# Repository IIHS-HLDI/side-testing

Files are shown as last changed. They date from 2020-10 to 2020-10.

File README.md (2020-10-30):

# Side testing

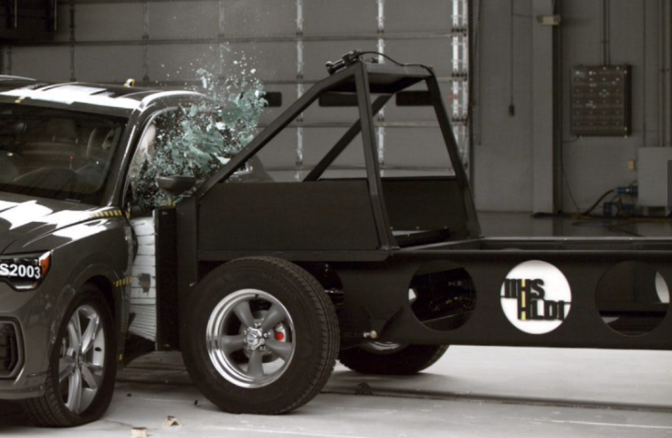
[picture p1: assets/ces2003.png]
Image of a crash test


This repository contains supporting documentation for the IIHS side impact crash test program.

## [2.0](2.0) - October 2020

In late 2020, the Institute began side impact testing using a new "2.0" protocol, which
features an improved impact cart and an impact speed of 60 km/h. This directory contains documentation
regarding the new protocol and manufacturing specs for the new impact cart.

## [1.0](1.0) - 2003 to 2020

This directory contains documentation regarding the Institute's original side impact crash test
program, in place since its inception in 2003.

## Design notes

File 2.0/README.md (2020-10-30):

# Side testing 2.0

In late 2020, the Institute began side impact testing using a new "2.0" protocol. The new protocol
features an improved impact cart traveling at 60 km/h, up from 50 km/h in the original side test protocol.

## Test protocol

- [Side impact 2.0 crash test protocol](Side%20impact%202.0%20test%20protocol.pdf) Version 1 (October 2020)

## Specifications

- [Moving deformable barrier 2.0 specification](Moving%20deformable%20barrier%20spec.pdf) Version 1 (October 2020)

## Impact cart design

- [Drawing package](Impact%20Cart/Drawing%20package.pdf)
- [Solid model](Impact%20Cart/Impact%20Cart%20with%20Suspension.STEP); Step A203 file of entire assembly for import
  into any 3D CAD software.
- DXF files for CNC plate cutting:
  - [Bent plate side channel](Impact%20Cart/Bent%20Plate%20Side%20Channel.DXF)
  - [Control arm tab](Impact%20Cart/Control%20Arm%20Tab.DXF)
  - [Low shock mounting plate](Impact%20Cart/Low%20Shock%20Mt%20Plate.DXF)
  - [Lower barrier stanchion gusset](Impact%20Cart/Lower%20Barrier%20Stanchion%20Gusset.DXF)
  - [Lower control frame tab](Impact%20Cart/Lower%20Control%20Frame%20Tab.DXF)
  - [Lower frame mount support](Impact%20Cart/Lower%20Frame%20Mt%20Support.DXF)
  - [Upper control frame mount](Impact%20Cart/Upper%20Control%20Frame%20Mount.DXF)
- [Detailed photos](Photos.md)

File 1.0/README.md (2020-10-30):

# Side testing 1.0

This is the Institute's original side impact test protocol dating back to 2003.

## Test protocol

- [Side impact 1.0 crash test protocol](Side%20crash%20test%20protocol%20-%20Version%20X.pdf) Version X (July 2017)

## Rating protocol

- [Rating guidelines](Rating%20guidelines.pdf) November 2016
- [Rating injury measure guidelines](Rating%20injury%20measure%20guidelines.pdf) Version III (May 2014)

## Miscellaneous

- [Moving deformable barrier specification](Moving%20deformable%20barrier%20spec.pdf)
- [Evaluation weighting principles for vehicle ratings](Weighting%20principles.pdf)
- [Outrigger assembly](Side%20impact%20outrigger%20assembly.pdf)
- [Recommended procedures for evaluating injury risk from side airbags](TWG%20side%20airbag%20evaluation%20procedures.pdf)
  July 2003; Prepared by the Side Airbag Out-of-Position Injury Technical Working Group (A joint project of Alliance,
  AIAM, AORC, and IIHS)
- [SID-IIs iliac wing](SID-IIs%20iliac%20wing.pdf) January 2007

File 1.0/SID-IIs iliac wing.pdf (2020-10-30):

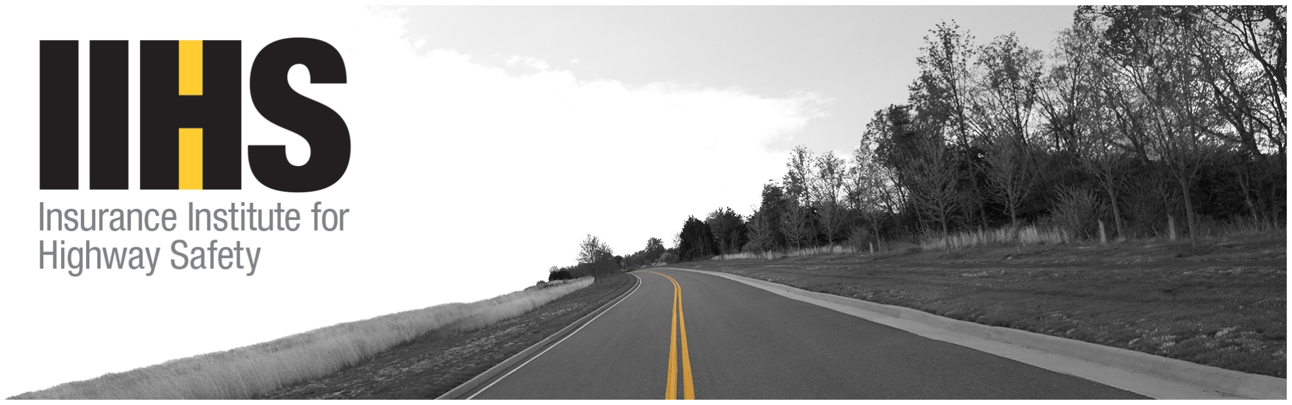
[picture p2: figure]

## Updated SID-IIs Iliac Wing

## January 2007

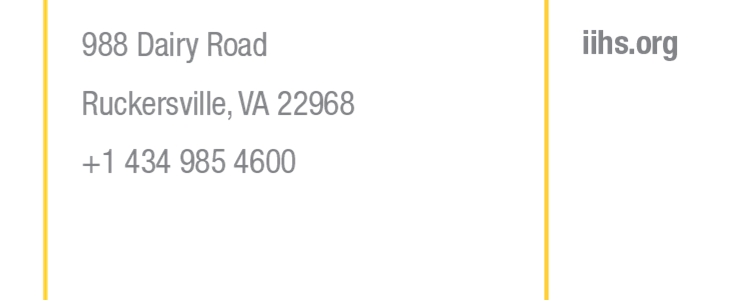
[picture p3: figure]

2007 Insurance Institute for Highway Safety | Updated SID-IIs Iliac Wing
988 Dairy Rd, Ruckersville, VA 22968. All rights reserved. | January 2007 1

Summary
A problem has been discovered with the original SID-IIs iliac wing design; the wing can deform over time and cause underreporting of iliac forces. The dummy supplier, First Technology Safety Systems (FTSS), has redesigned the wing to fix the problem. Updated iliac wings can be ordered directly from FTSS. SID-IIs dummies used in future Insurance Institute for Highway Safety (IIHS) side crash tests will have the updated iliac wing design.
Iliac Wing Load Path Issue
Problem: In the SID-IIs dummy, the iliac wing is attached to the iliac load cell with four mounting bolts. These bolts push on a thin steel plate molded into the iliac wing, which serves to distribute the load to the load cell (Figure 1). However, the plate is separated from the load cell by 3 mm (0.125 in) of urethane. Figure 2 shows a new/undeformed iliac wing mounted on a load cell (the areas of the wing designed to contact the load cell are shown with orange highlight). Over time, the 3 mm section of urethane deforms under pressure and eventually contacts the center of the load cell (shown with blue highlight). This causes the input force to bypass the correct load path and results in underreporting of the true force value. Figure 3 shows an example of a severely deformed iliac wing.
Solution: FTSS has worked with the Occupant Safety Research Partnership (OSRP) SID-IIs Upgrade Task Group to address the iliac wing deformation, or creep, problem. The FTSS solution uses metal standoffs in the iliac wing to prevent any contact between the urethane and load cell. With the updated design, the attachment force passes from the mounting bolt heads to the load cell through the metal standoffs (Figure 4). An additional iliac wing design change was modification to the urethane material (see section below). Part numbers 180-4322-1 (left iliac wing) and 180-4322-2 (right iliac wing) can be used to order the replacement wings from FTSS.
Iliac Wing Material Change
The original urethane formula (Material 1) for the iliac wing was used from 1994 until April 2004 when it was discontinued. It was replaced with a new urethane formula (Material 2), but stiffness tests showed Material 2 to be considerably less stiff than the original (Figure 5). Discovery of this problem lead to a new urethane formula (Material 3) with stiffness similar to the original (Figure 6). Ongoing research by the OSRP SID-IIs Upgrade Task Group is assessing the differences between Material 1 and Material 3 using dynamic loading conditions.
Note: The recent National Highway Traffic Safety Administration (NHTSA) SID-IIs final rule for 49 CFR Part 572 (Docket No. NHTSA 25442) specifies an iliac wing made from Material 2 without standoffs. IIHS will petition NHTSA to change the specification to the solution recommended by FTSS and the OSRP SID-IIs Upgrade Task Group (Material 3 with standoffs).

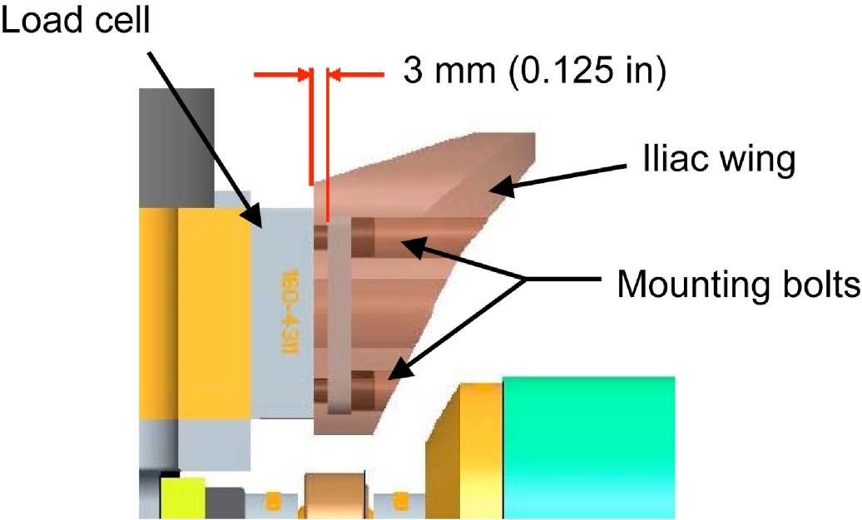
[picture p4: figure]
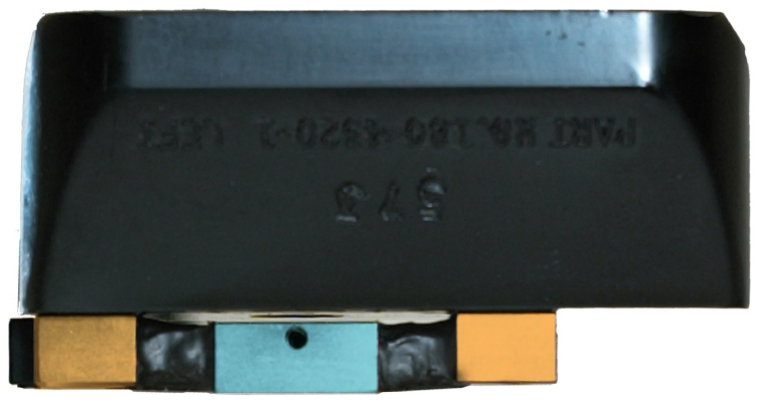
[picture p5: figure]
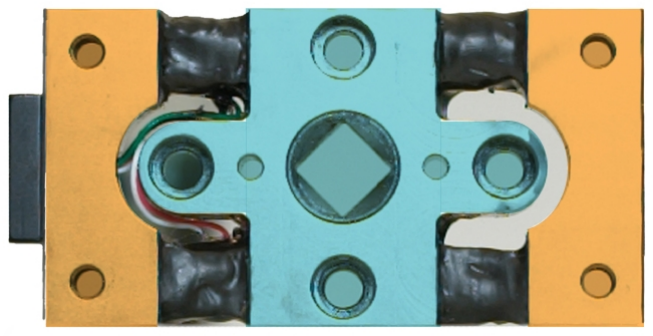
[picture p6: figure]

988 Dairy Rd, Ruckersville, VA 22968. All rights reserved. | January 2007 2

Figure 1
SID-IIs Iliac Wing (Original) Attached to Iliac Load Cell (Anterior-Posterior View)

Figure 2
Superior-Inferior View of Iliac Load Cell and Iliac Wing (Top Photo) and Lateral-Medial View of Load Cell (Bottom Photo)

Note the normal gap between the iliac wing and center of the load cell. Tightening of the attachment bolts causes the ends of the load cell (orange highlight) to creep into the wing. Over time, there is sufficient creep (about 2 mm) for the wing to load the center of the load cell (blue highlight). This allows an externally applied force to bypass the correct load path.

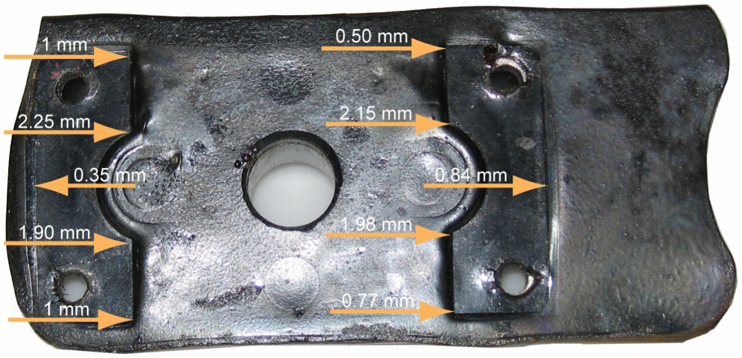
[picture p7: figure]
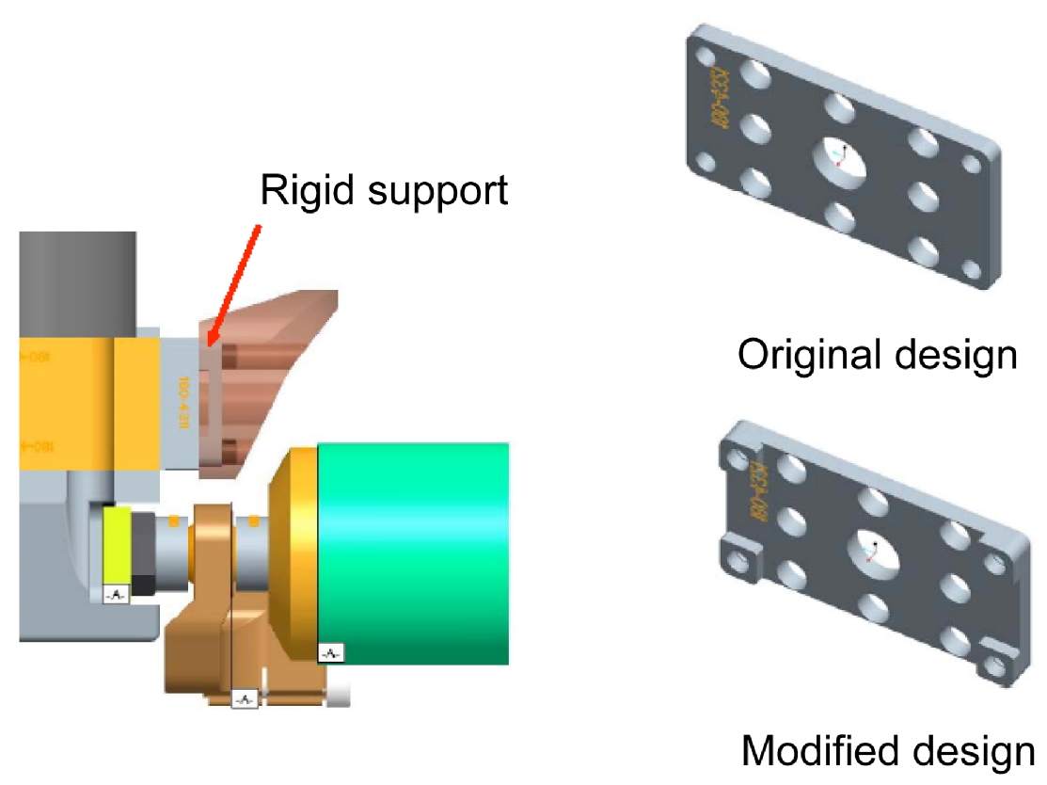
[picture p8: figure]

988 Dairy Rd, Ruckersville, VA 22968. All rights reserved. | January 2007 3

Figure 3
Deformed Iliac Wing Showing Measured Creep Levels

Figure 4
Modified Iliac Wing Design with Built-In Metal Standoffs

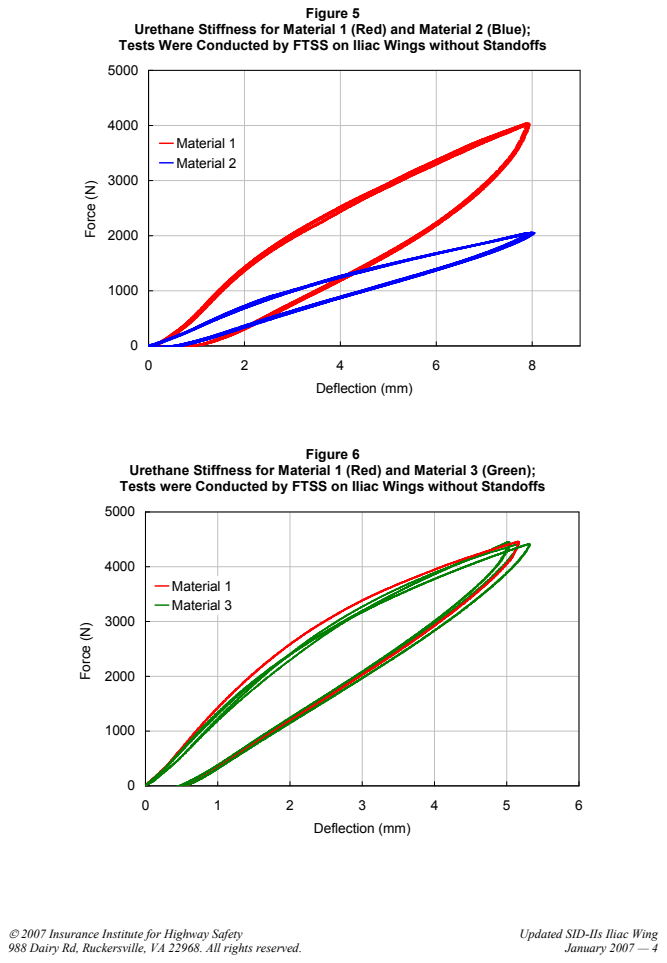
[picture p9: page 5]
988 Dairy Rd, Ruckersville, VA 22968. All rights reserved.; January 2007  4; Figure 5; Figure 6; Material 1 Material 2; Material 1 Material 3

Urethane Stiffness for Material 1 (Red) and Material 2 (Blue);
Tests Were Conducted by FTSS on Iliac Wings without Standoffs

Deflection (mm) Force ⁽N⁾

Urethane Stiffness for Material 1 (Red) and Material 3 (Green);
Tests were Conducted by FTSS on Iliac Wings without Standoffs

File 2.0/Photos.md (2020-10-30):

# Impact cart photos

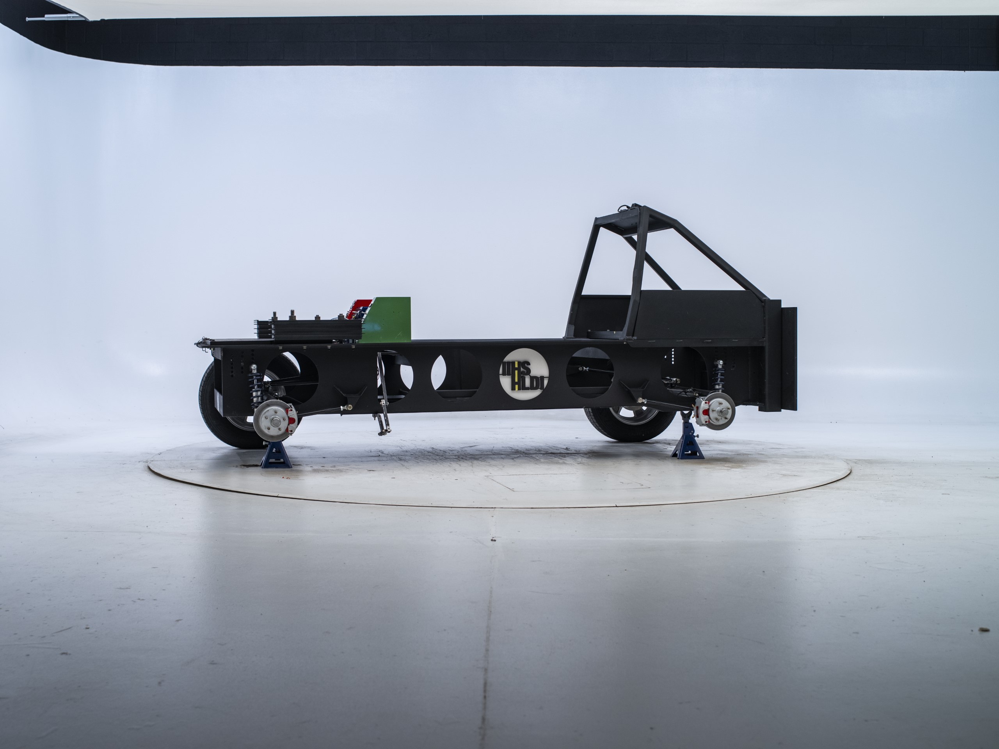
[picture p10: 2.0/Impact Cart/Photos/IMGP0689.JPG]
"Photo of impact cart"

*IMGP0689.JPG*

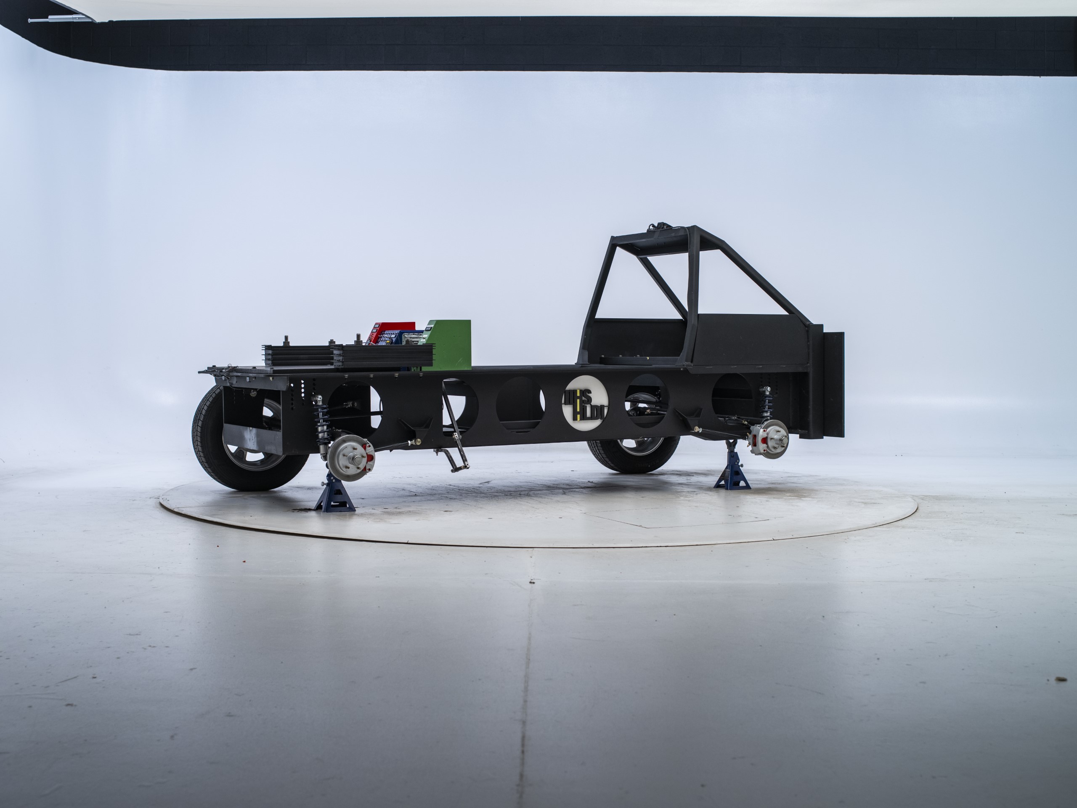
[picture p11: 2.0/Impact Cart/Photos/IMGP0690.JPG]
"Photo of impact cart"

*IMGP0690.JPG*

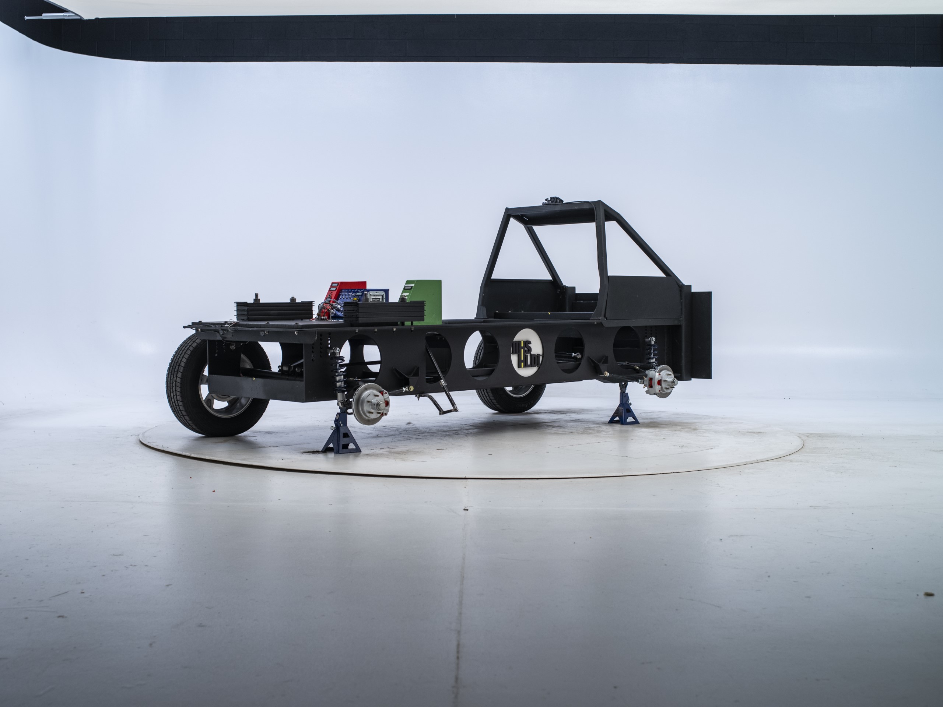
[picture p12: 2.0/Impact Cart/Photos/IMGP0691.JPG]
"Photo of impact cart"

*IMGP0691.JPG*

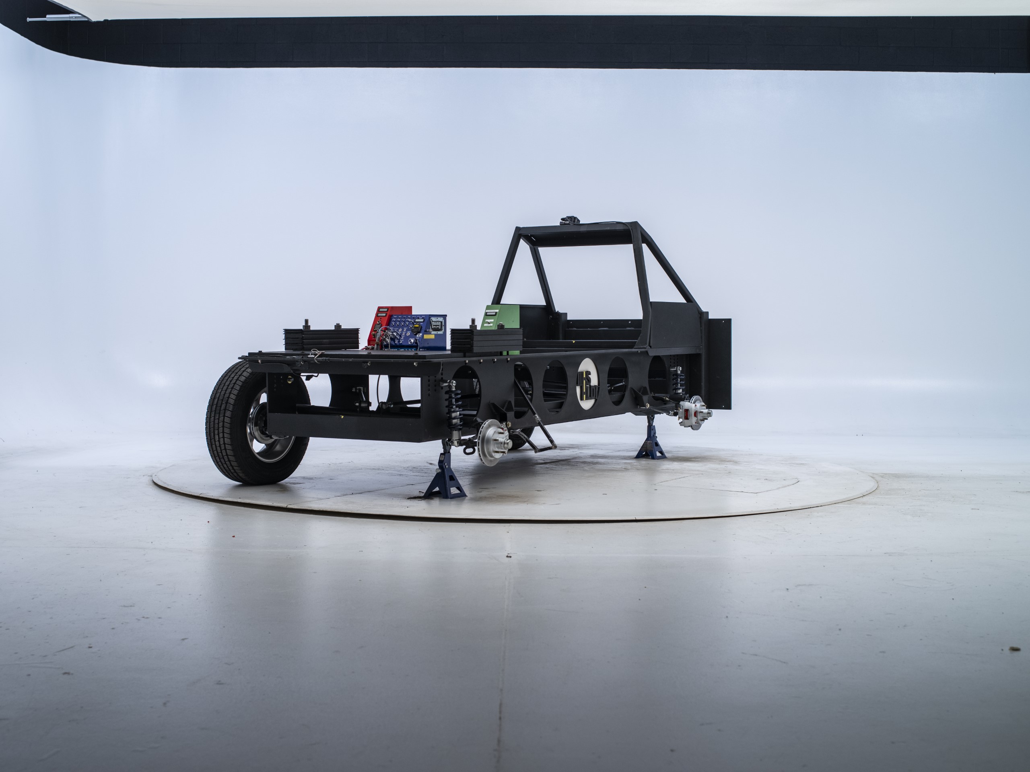
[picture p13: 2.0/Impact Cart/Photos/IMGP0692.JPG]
"Photo of impact cart"

*IMGP0692.JPG*

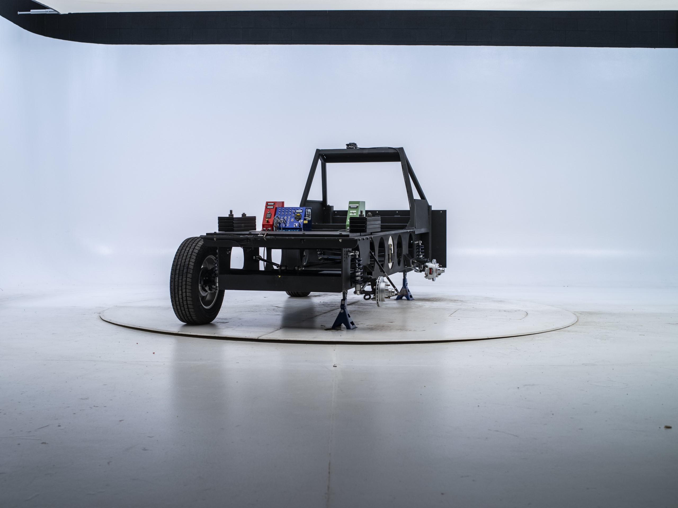
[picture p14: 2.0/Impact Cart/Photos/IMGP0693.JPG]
"Photo of impact cart"

*IMGP0693.JPG*

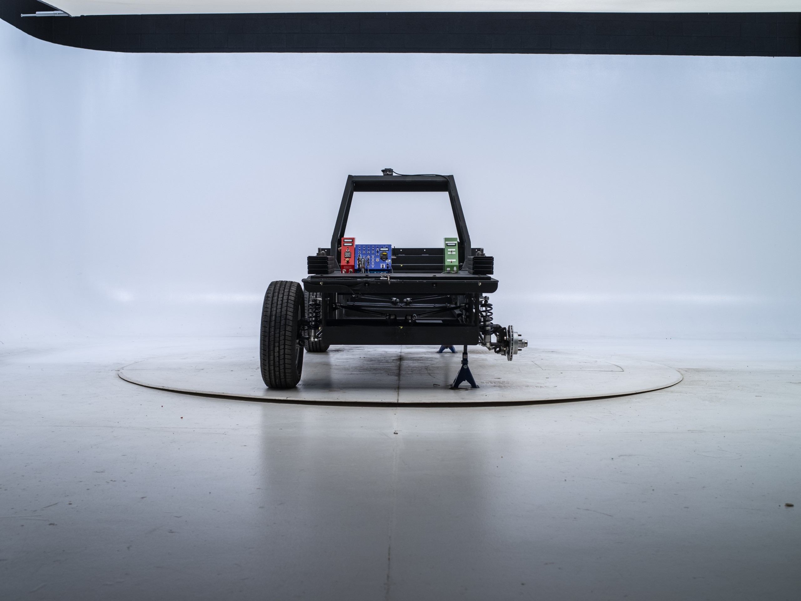
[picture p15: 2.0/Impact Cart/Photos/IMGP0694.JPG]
"Photo of impact cart"

*IMGP0694.JPG*

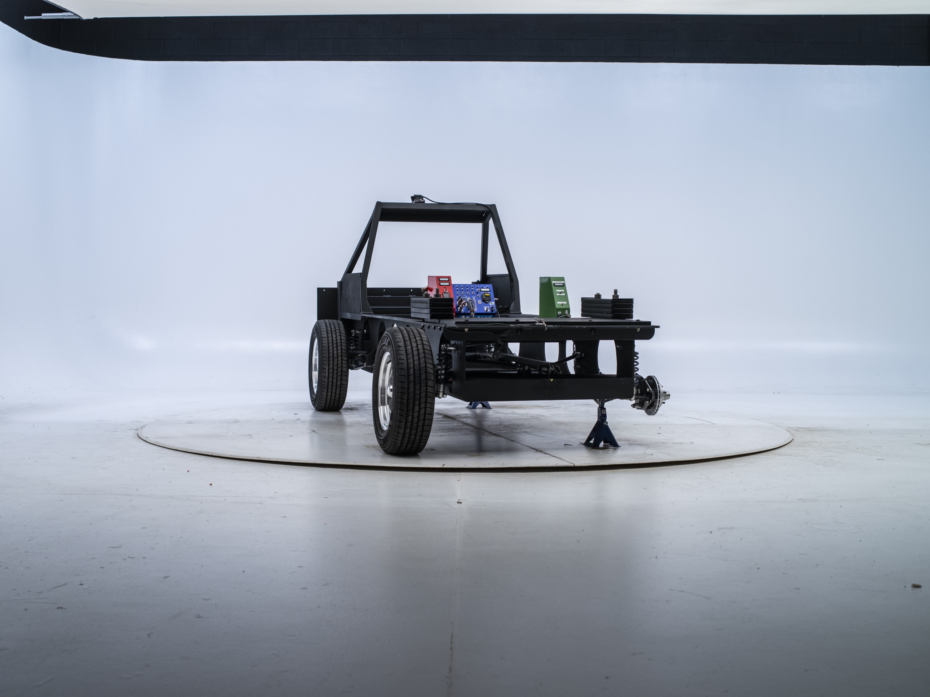
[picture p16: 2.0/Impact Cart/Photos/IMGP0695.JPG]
"Photo of impact cart"

*IMGP0695.JPG*

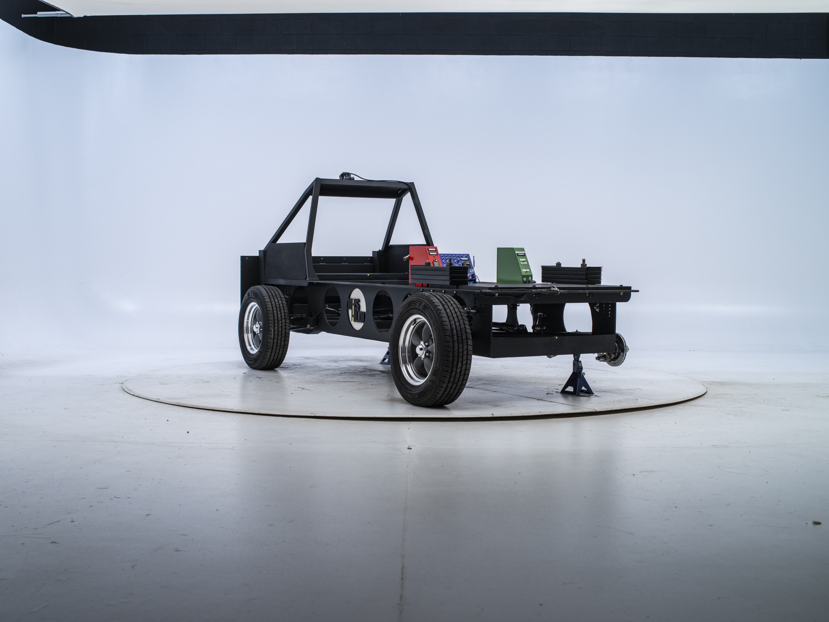
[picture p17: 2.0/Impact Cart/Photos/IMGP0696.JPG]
"Photo of impact cart"

*IMGP0696.JPG*

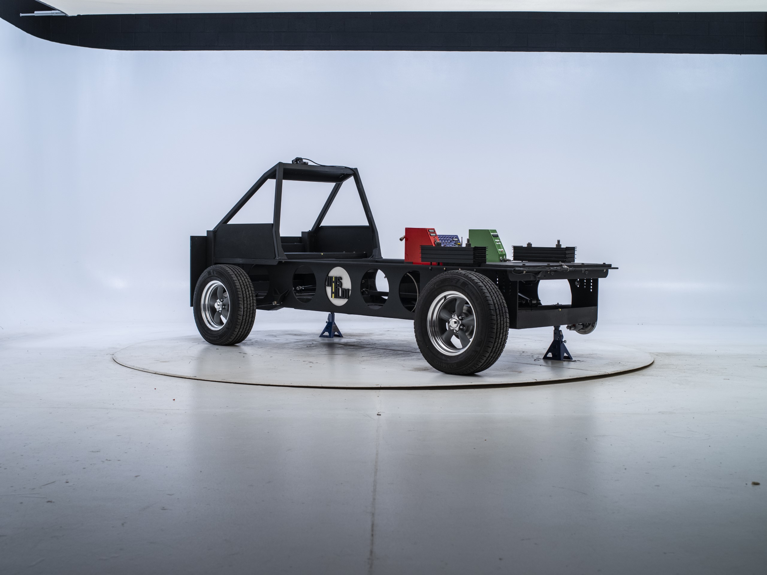
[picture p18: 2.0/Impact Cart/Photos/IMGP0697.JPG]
"Photo of impact cart"

*IMGP0697.JPG*

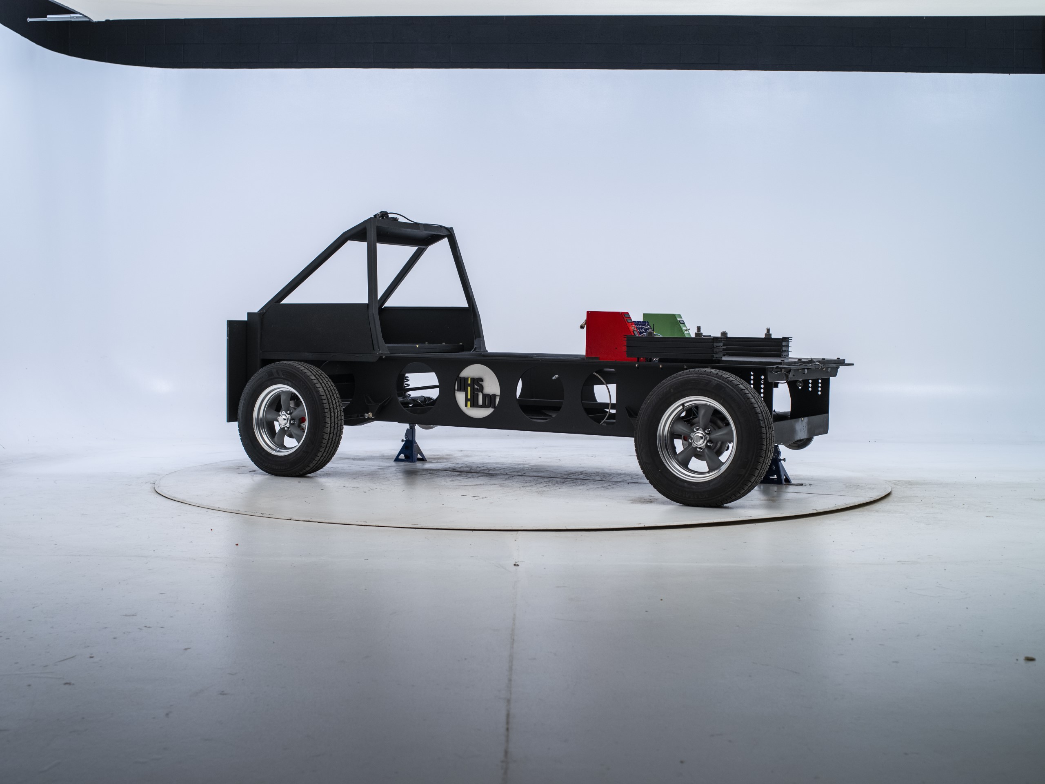
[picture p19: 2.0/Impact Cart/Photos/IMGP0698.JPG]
"Photo of impact cart"

*IMGP0698.JPG*

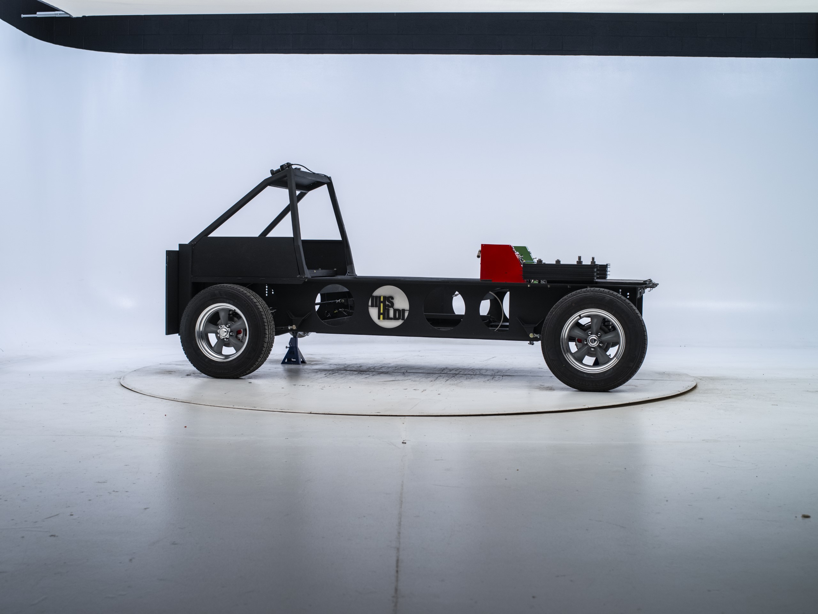
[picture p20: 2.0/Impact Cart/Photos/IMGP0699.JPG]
"Photo of impact cart"

*IMGP0699.JPG*

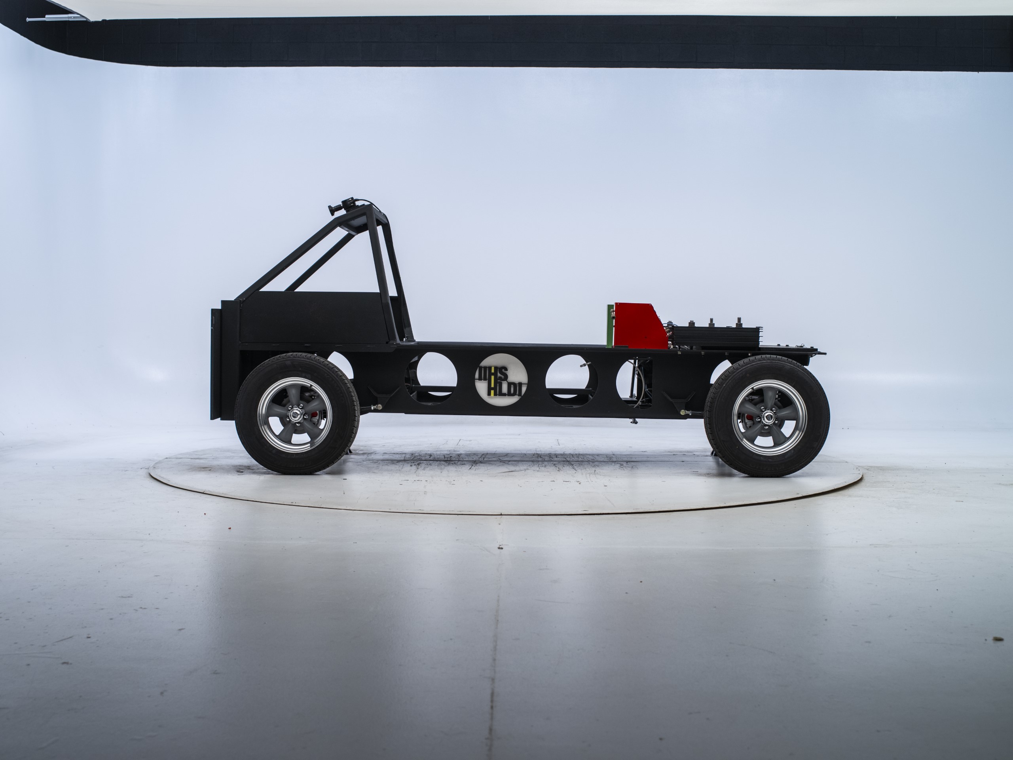
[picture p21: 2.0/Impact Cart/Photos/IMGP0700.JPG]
"Photo of impact cart"

*IMGP0700.JPG*

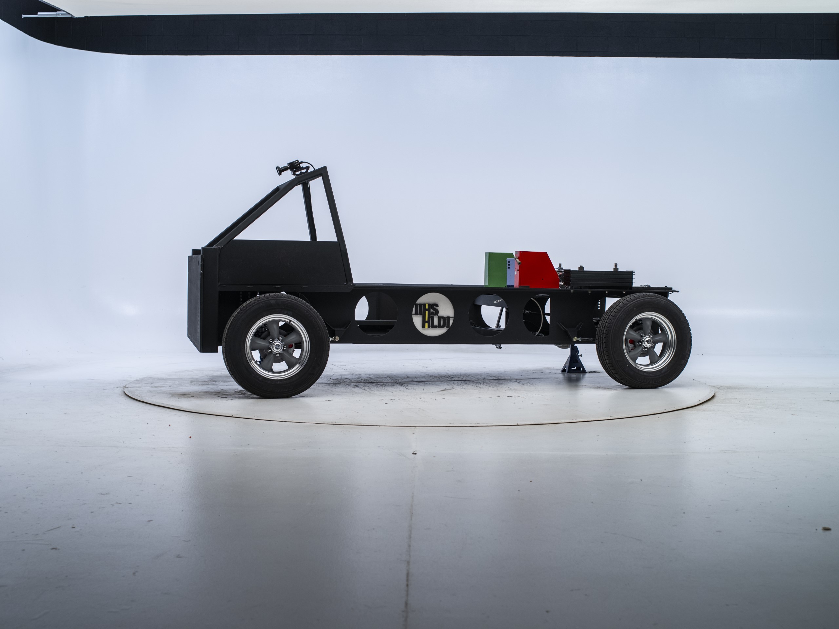
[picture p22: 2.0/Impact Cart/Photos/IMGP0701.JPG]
"Photo of impact cart"

*IMGP0701.JPG*

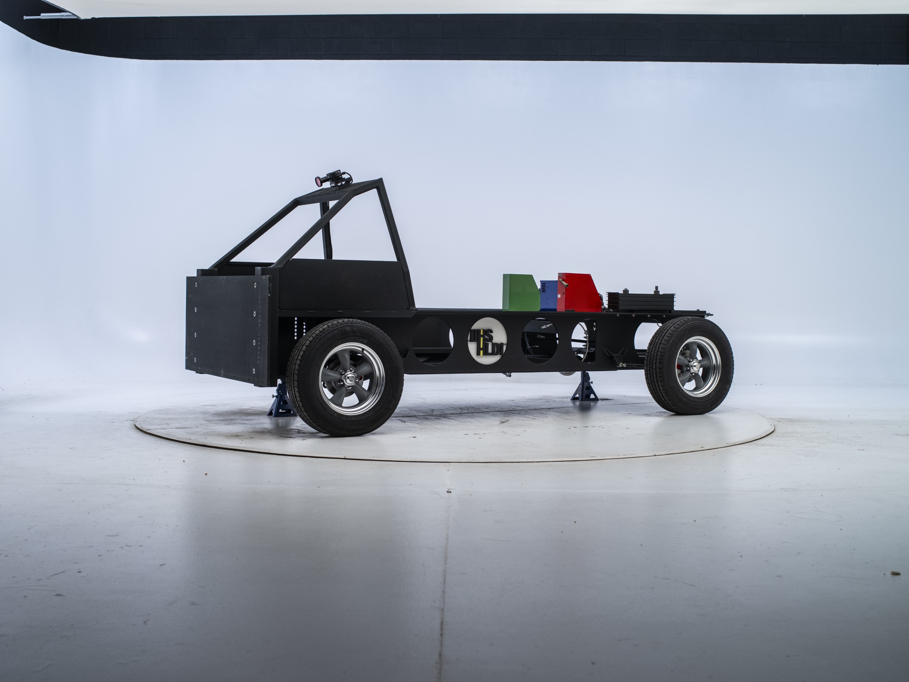
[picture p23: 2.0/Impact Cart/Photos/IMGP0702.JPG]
"Photo of impact cart"

*IMGP0702.JPG*

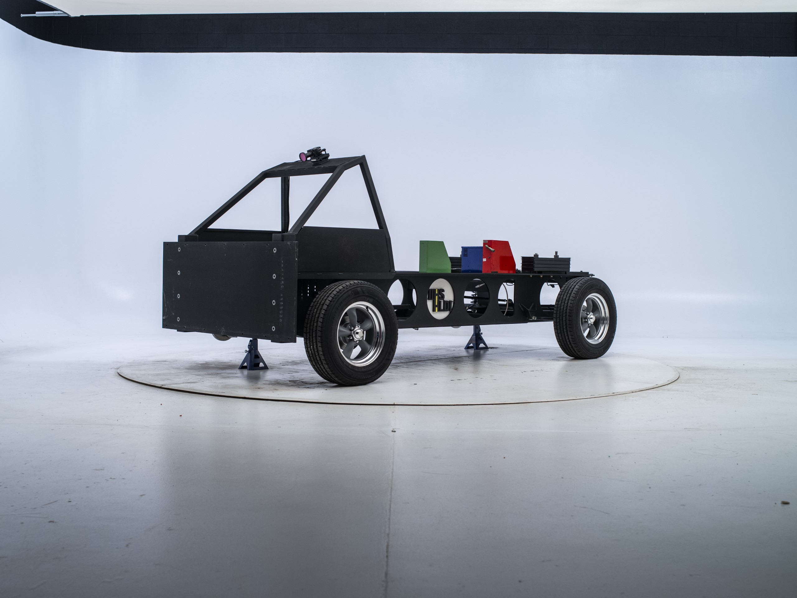
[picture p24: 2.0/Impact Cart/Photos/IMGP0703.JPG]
"Photo of impact cart"

*IMGP0703.JPG*

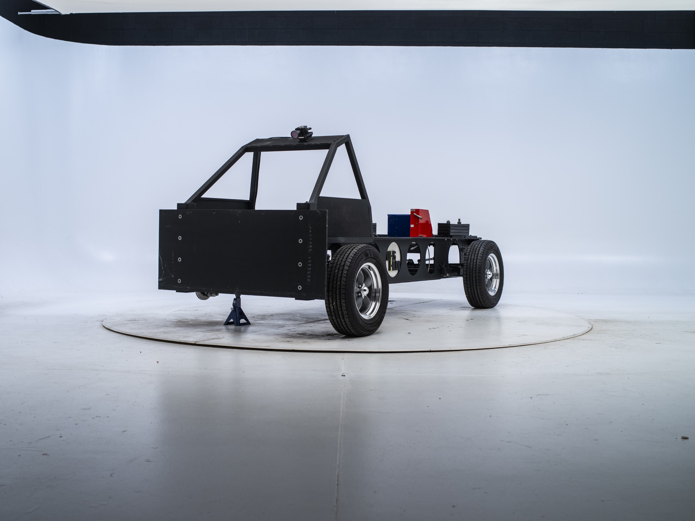
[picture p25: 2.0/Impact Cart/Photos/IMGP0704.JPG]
"Photo of impact cart"

*IMGP0704.JPG*

"Photo of impact cart"
*IMGP0705.JPG*

"Photo of impact cart"
*IMGP0706.JPG*

"Photo of impact cart"
*IMGP0707.JPG*

"Photo of impact cart"
*IMGP0708.JPG*

"Photo of impact cart"
*IMGP0709.JPG*

"Photo of impact cart"
*IMGP0710.JPG*

"Photo of impact cart"
*IMGP0711.JPG*

"Photo of impact cart"
*IMGP0712.JPG*

"Photo of impact cart"
*IMGP0714.JPG*

"Photo of impact cart"
*IMGP0715.JPG*

"Photo of impact cart"
*IMGP0716.JPG*

"Photo of impact cart"
*IMGP0717.JPG*

"Photo of impact cart"
*IMGP0718.JPG*

"Photo of impact cart"
*IMGP0719.JPG*

"Photo of impact cart"
*IMGP0720.JPG*

"Photo of impact cart"
*IMGP0721.JPG*

"Photo of impact cart"
*IMGP0722.JPG*

"Photo of impact cart"
*IMGP0723.JPG*

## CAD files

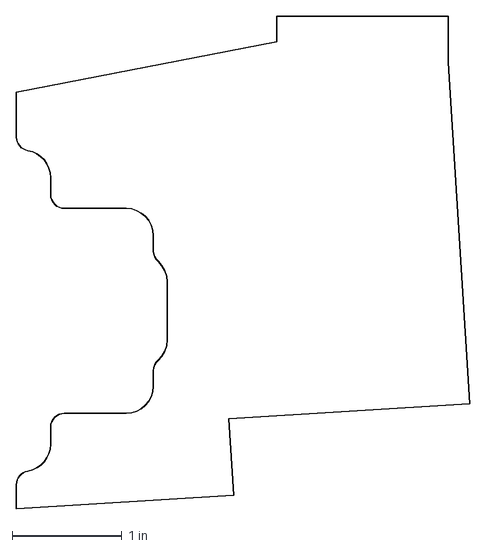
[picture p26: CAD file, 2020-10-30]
2.0/Impact Cart/Low Shock Mt Plate.DXF
4.13 x 4.49 in

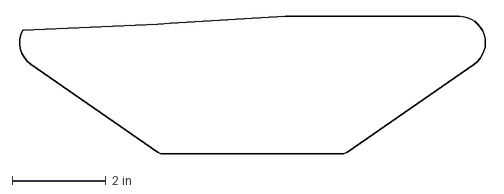
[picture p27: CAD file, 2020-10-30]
2.0/Impact Cart/Lower Frame Mt Support.DXF
10.1 x 2.94 in

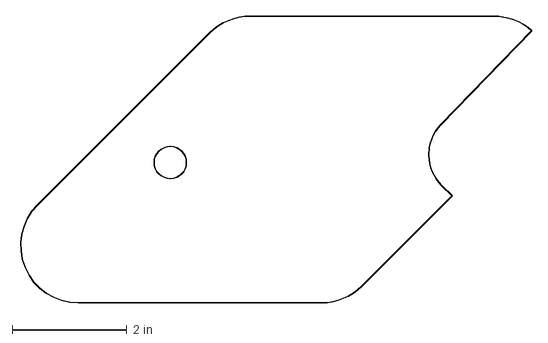
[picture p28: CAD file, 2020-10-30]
2.0/Impact Cart/Lower Barrier Stanchion Gusset.DXF
8.99 x 5.00 in

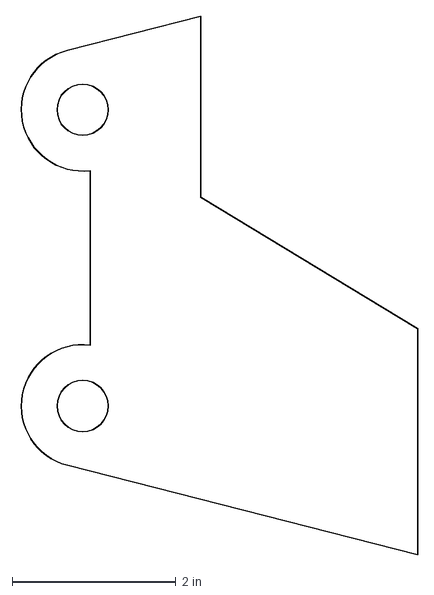
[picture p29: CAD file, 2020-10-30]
2.0/Impact Cart/Upper Control Frame Mount.DXF
4.90 x 6.58 in

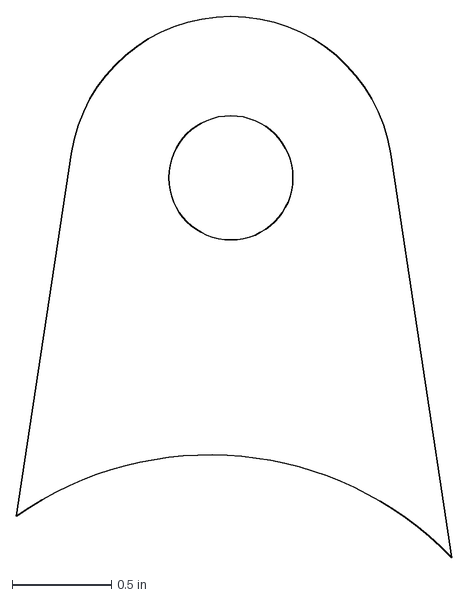
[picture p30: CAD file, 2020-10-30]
2.0/Impact Cart/Control Arm Tab.DXF
2.19 x 2.72 in

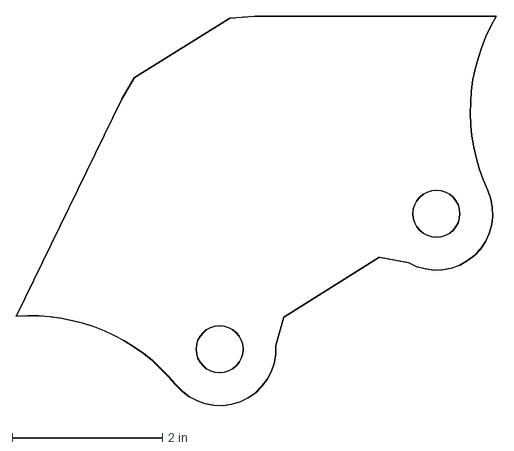
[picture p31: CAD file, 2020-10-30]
2.0/Impact Cart/Lower Control Frame Tab.DXF
6.41 x 5.24 in

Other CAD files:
2.0/Impact Cart/Bent Plate Side Channel.DXF

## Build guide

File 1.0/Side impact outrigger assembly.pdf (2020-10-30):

IIHS Side Impact Outrigger

Assembly Procedure

Base Assembly (14.3 lbs)
The base assembly consists of a ¼” thick steel plate, a ¼” thick piece of polyethylene, and mounting fixtures for the upper and lower arms. The plate (P1) measures 10” x 13.5,” with the long edges running parallel to the vehicle. The edge facing away from the vehicle was bent upward slightly. The UHMW polyethylene (P2) is attached to the bottom of the plate with screws recessed into this upturned edge.
The two mounting brackets for the lower arms (P20) were machined from a 1-5/8” diameter bar of mild steel. They were then tapped at ½”-13, for the allen cap screws (P14). These brackets were welded to P1 around their edges.
The two mounting brackets for the upper arm were cut from 2” x 2” x 3/8” angle iron (P19). ½” holes were drilled through the upper portions for a bolt to secure them to the lower arm. These brackets were welded to P1 around their edges.

Upper Arm (27.0 lbs)
The upper arm consists mainly of outer (P3) and inner (P4) poles of chromemoly tubing, two die springs (P7 and P8), two pieces of angle iron (P19) for securing the assembly to the B-pillar of the vehicle, and fixtures for mounting the arm to the base and the angle iron.
The outer pole (P3) is 4130 chromemoly tubing with an outside diameter of 1½” and a length of 56”. A tube cap (P11) has been machined out of mild steel to fit inside the lower end of the pole. This cap was welded to the pole, and a hole was drilled through both to accommodate a ½” bolt securing the pole to the mounting brackets on the base assembly. Four steel washers were used as well, one on each side of both brackets. Two die springs were placed inside the outer tube to decreases the rate of impact on the plate and floor. The outer spring (P7) has a spring constant of 52.4 lbf/in, and is 20” long. The second spring (P8) was placed inside the first, has a spring constant of 32.1 lbf/in, and is 23” long. The extra length of the inner spring allows for a preload to be placed on the upper arm when securing the assembly to the vehicle. Both springs sit on the tube cap (P11) at the lower end of the outer pole.
The inner pole (P4) is 4130 chromemoly tubing with an outside diameter of 1¼” and a length of 41”. A tube cap (P11) has been machined out of mild steel to fit inside the lower end of the pole. This cap was welded to the pole, and a round groove, ¼” deep and ¾” in diameter, was machined into the outside of the cap in order to seat the inner spring (P8) for stability during loading.
At the vehicle end of the inner pole (P4), a tube cap (P11) was machined and tapped to accommodate a ½” ball joint (P10). This cap has been welded to the pole and a ½” nut is used for making adjustments when securing the assembly to the vehicle. Two pieces of 2” x 2” x 3/8” angle iron (P19) are used to grip the B-pillar of the vehicle. Each was cut 12” long and drilled with three ½” holes near each end to allow a good fit on Bpillars of different widths. Two steel brackets (P16) were cut from 3/8” mild steel, drilled with ½” holes, and welded to the inside of one of the pieces of angle iron. The ball joint (P10) from the upper arm is fixed between these two brackets with a bolt. Two spacers (P17) were machined from mild steel to secure the ball joint in the middle of the two brackets, allowing it a greater range of motion.
When secured to the vehicle, the upper edge of the angle iron rests against or near the roof of the car to prevent the assembly from sliding upward during impact. Additionally, a piece of urethane rubber (P22), 3/8” thick, has been fixed with contact cement along the length of each piece of angle iron to ensure a tight grip on the B-pillar. On each side of the B-pillar, one 6” long bolt is used with steel washers for tightening the assembly to the B-pillar.

Lower Arms (short arm: 10.0 lbs; long arm: 15.0 lbs; 2 gator clamps: 13.7 lbs each)
The assembly has two lower arms, each of which consist mainly of an outer (P3) and inner (P4) pole, an acme-threaded rod (P5) for adjusting the overall length of the arm, gator jaws (P9) for securing to the frame of the vehicle, and mounting fixtures for each end of the arm. With the exception of the lengths of the poles and the acme rods, the two lower arms are identical.
The outer (P3) and inner (P4) poles are 4130 chromemoly tubing. The tube used for the outer pole has an outside diameter of 1½”, with 1¼” for the inner pole. The length of each pole used for the arm that will attach to the forward end of the vehicle is 40”, with 25” lengths for the arm attaching to the rearward end. The lengths of acme-threaded rod are the same as the poles, with 40” for the forward arm and 25” for the rearward.
The lower arms are fixed to the base using a piece of rectangular steel stock (P12), a tapped block of mild steel (P13), a ½” ball joint (P10), and an allen cap screw (P14). The 1” x 2” x 1/8” rectangular tube stock (P12) was cut diagonally lengthwise to fit to the underside of the lower arm, and to leave a rectangular section near the end of the pole. The mild steel block (P13) was tapped to fit the threaded end of the ½” ball joint (P10), and then welded along the bottom and rear edges inside this rectangular section. The entire piece of stock was then welded along its edges to the outer pole. The allen cap screw (P14) fastens the ball joint to the bracket on the base assembly. A ½” nut is used to lock the ball joint when securing the device to a vehicle.
A 5/8” acme-threaded rod (P5) and acme coupling nuts (P6) are used for adjusting the lengths of the lower arms. Two of the coupling nuts were cut in half, the other two used at their full length; each arm requires two half-length nuts and one full-length nut. A steel cap (P11) was machined to fit inside the lower pole, with a hole for the acme rod to pass through. One of the half-length coupling nuts was welded to the acme rod on the outside of the pole. A second half-length coupling nut was fastened to the rod on the inside of the pole with a 1/8” roll pin passing through the nut and the threads of the rod, so that the acme rod inside the pole would not be weakened from drilling. The full-length coupling nut was welded in the end of the inner pole. Additionally, a ½” hole was drilled through the pole 1” from the end on opposite sides of pole, and lugs welded to the coupling nut. With this assembly, adjustments are made to the arm length by turning the coupling nut on the outside end of the arm, thereby moving the inner pole within the outer pole. Steel washers were placed on either side of the steel cap for ease of movement.
The lower arms are fastened to the vehicle using gator jaws (P9) clamped to the pinch welds on the car. The gator jaws were ordered with an attached angle bracket, to which an additional 3/8” steel bracket (P16) was welded. A steel cap (P11) was machined and tapped to accommodate the ½” ball joint (P10). A ½” hole was drilled through the pole 1” from the end on opposite sides of pole, and lugs welded to the cap. A ½” bolt was fastened through a hole drilled in the steel bracket and through the hole of the supplied angle bracket in order to secure the ball joint. Steel spacers (P17) were machined to secure the ball joint in the middle of the bracket and to allow it greater freedom of movement. A ½” nut is used to lock the ball joint when securing the device to a vehicle.

Parts List

P1: ¼” Steel Plate; 10” x 13.5”
P2: ¼” Premium UHMW Polyethylene; McMaster-Carr Part #84765K213; 10” x 13.5” P3: 4130 Chromemoly Tubing; O.D. 1.5”, 0.095” wall thickness; one 25” length, one 40” length, one 56” length; A.E.D. Motorsport Products,
www.aedmotorsport.com
P4: 4130 Chromemoly Tubing; O.D. 1.25”, 0.12” wall thickness; one 25” length, one 40” length, one 41” length; A.E.D. Motorsport Products, www.aedmotorsport.com
P5: 5/8”-8 Acme Threaded Rod, Grade B7 Alloy Steel; McMaster-Carr Part #93410A130
P6: 5/8”-8 Acme Coupling Nut, Plain Steel; McMaster-Carr Part #93023A662; 4 nuts, two cut in half
P7: Continuous-Length Oil-Tempered Steel Die Spring; k=52.4 lbf/in; McMaster-Carr Part #9621K29; length=20”
P8: Continuous-Length Oil-Tempered Steel Die Spring; k=32.1 lbf/in; McMaster-Carr Part #9621K18; length=23”
P9: Gator Jaws with Angle Bracket; Mo-Clamp Part #4015; 2 Assemblies
P10: ½”-20 Ball Joint with Rod End; McMaster-Carr Part #60645K16; 5
P11: Machined Mild Steel Tube Cap; 7
P12: 1”x 2”x 1/8” Rectangular Steel Tube Stock; two 6” long sections, cut diagonally P13: ¾” Mild Steel Block, Tapped; 2
P14: ½”-13 Allen Cap Screw; 2
P15: Steel Washer
P16: 3/8” Machined Mild Steel Brackets; 2
P17: Machined Mild Steel Spacer; 6
P18: ½” Bolt; ½” Nut
P19: 2”x 2”x 3/8” Angle Iron; two 3” lengths, two 12” lengths
P20: Machined, Tapped Steel Mounting Brackets, Lower Arms; O.D. 1.625”; 2 P21: 1/8” Roll Pin; 2
P22: 3/8” Urethane Rubber Pad; 2

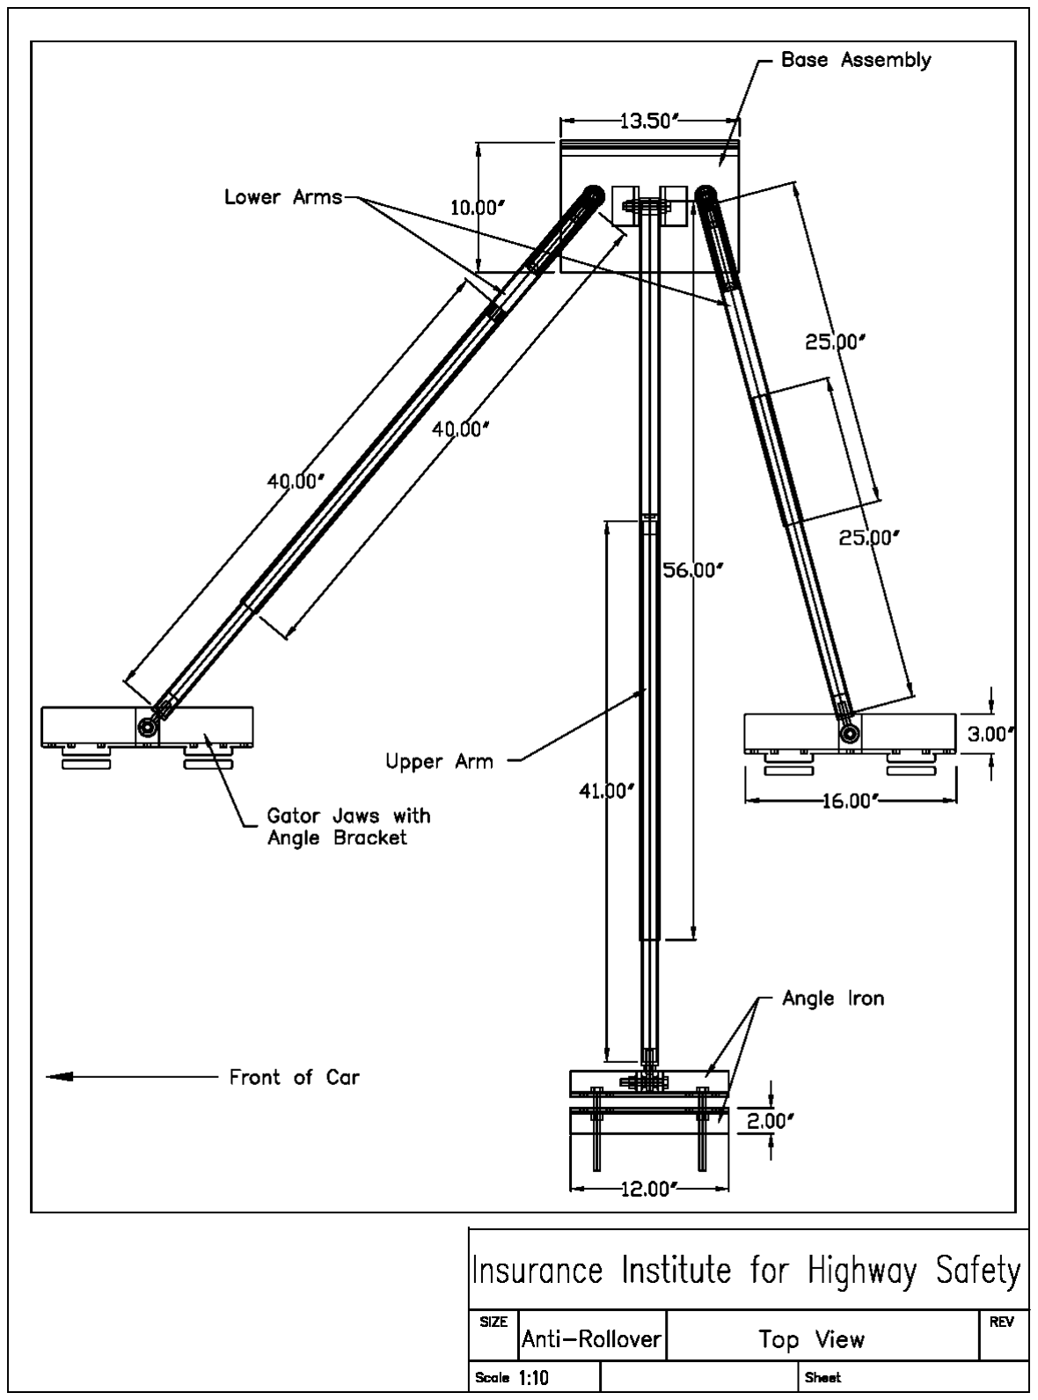
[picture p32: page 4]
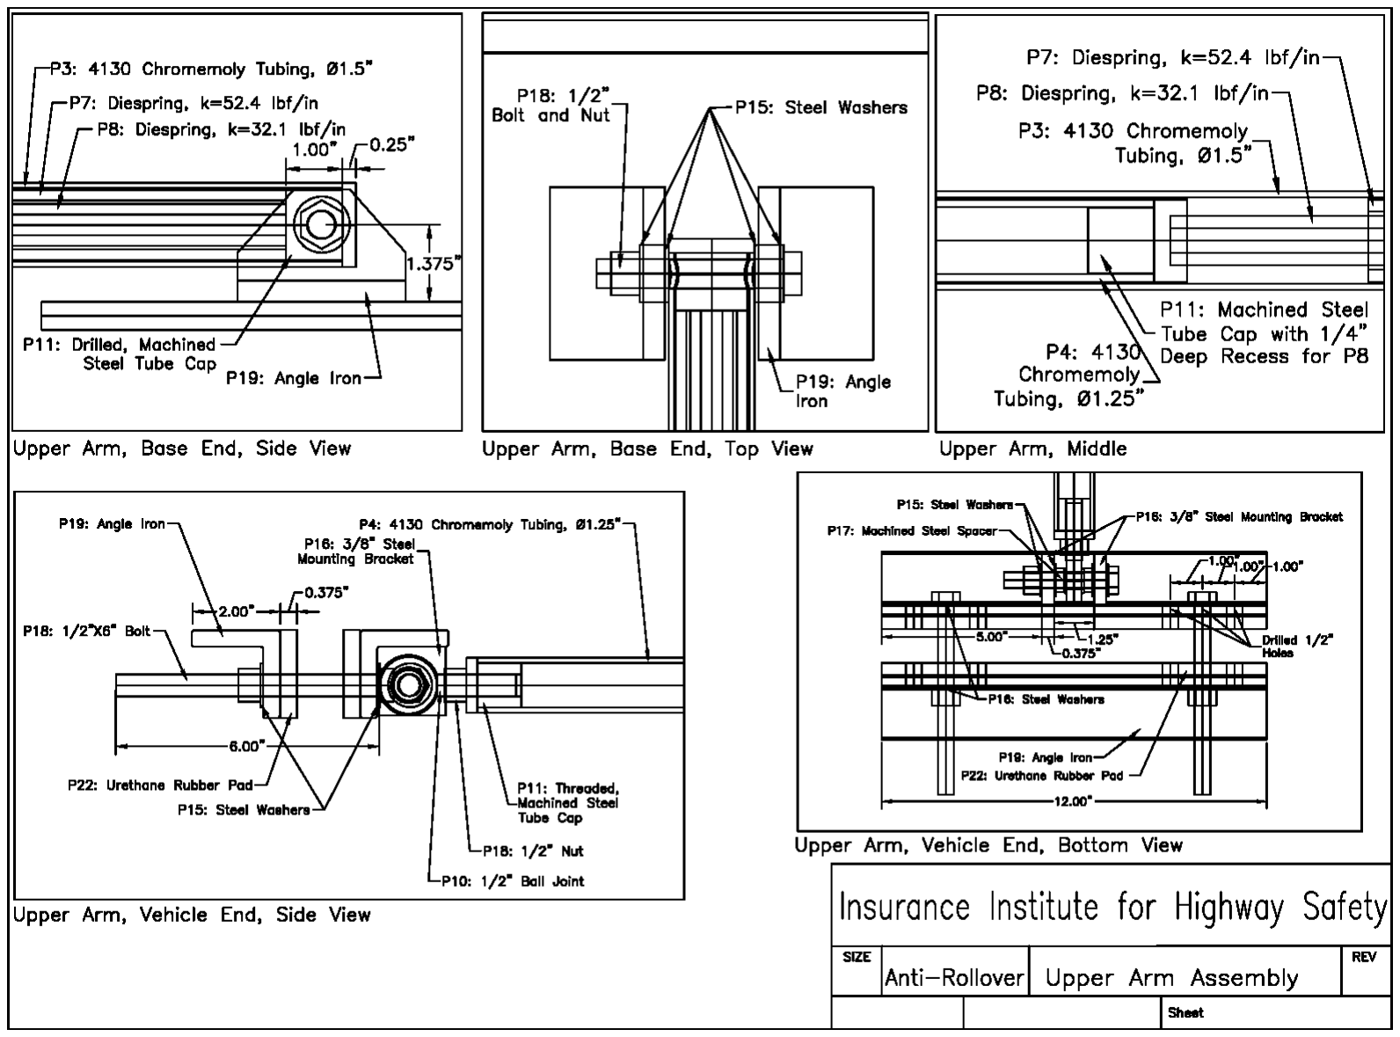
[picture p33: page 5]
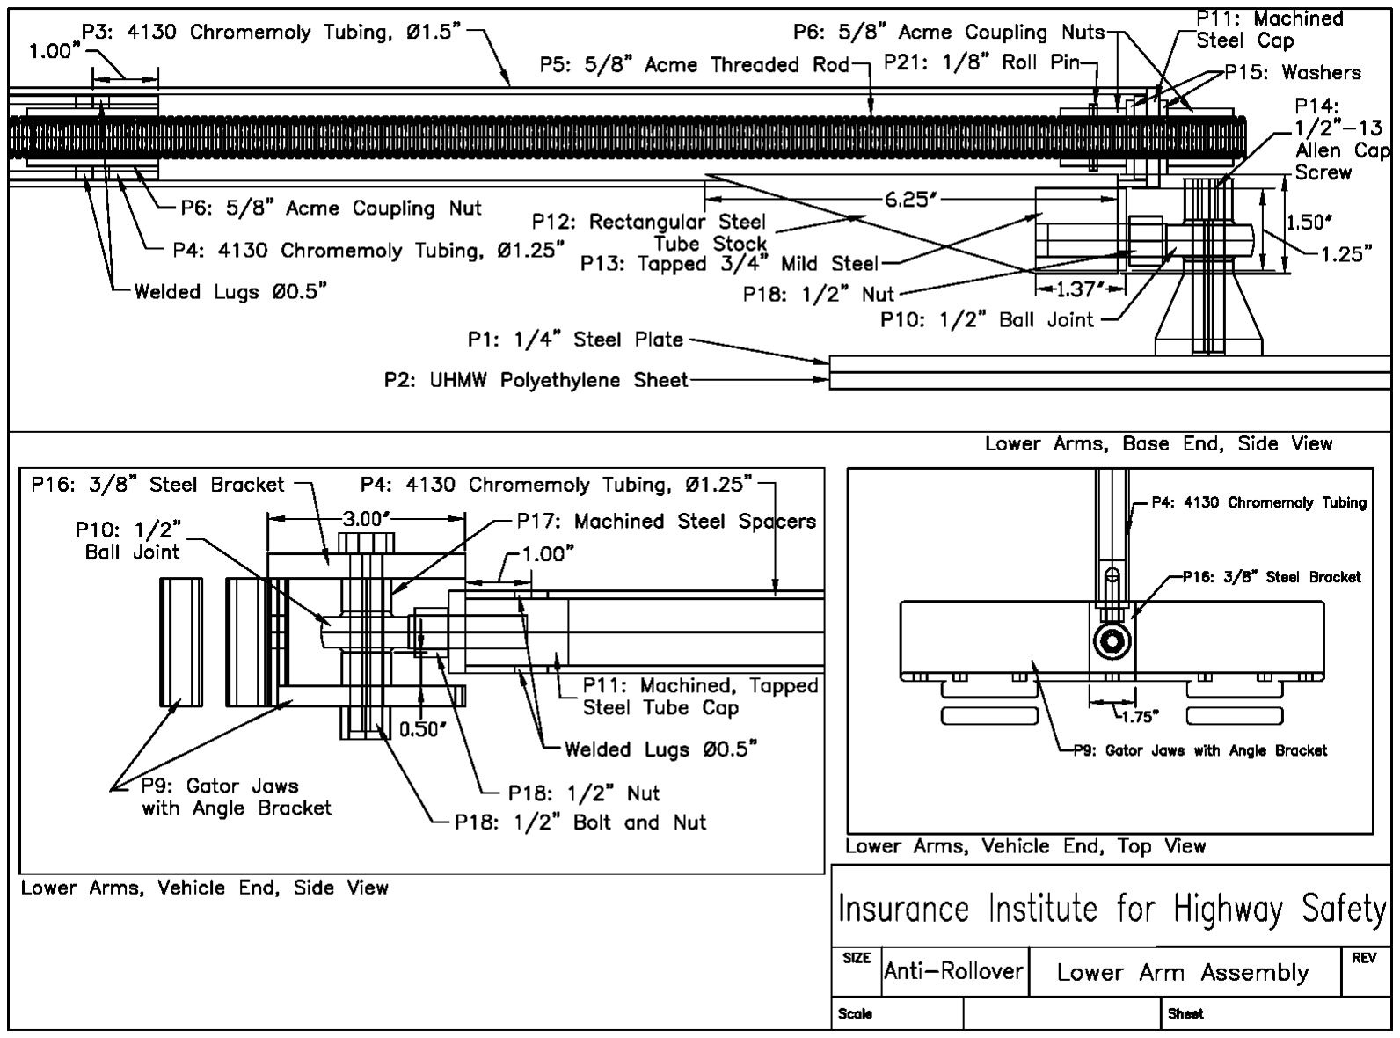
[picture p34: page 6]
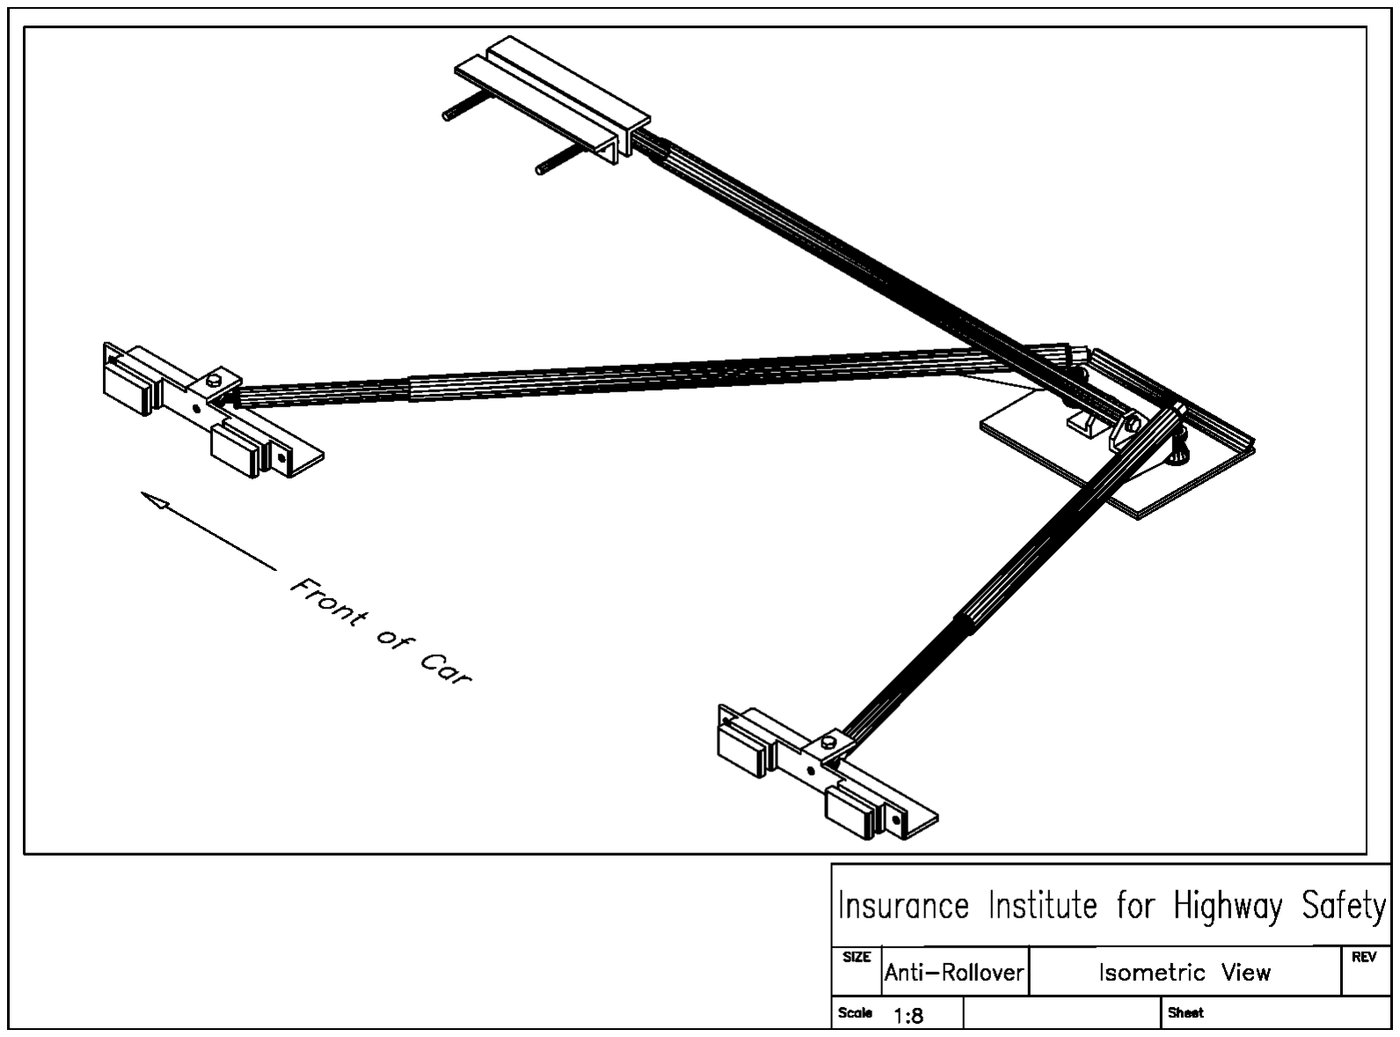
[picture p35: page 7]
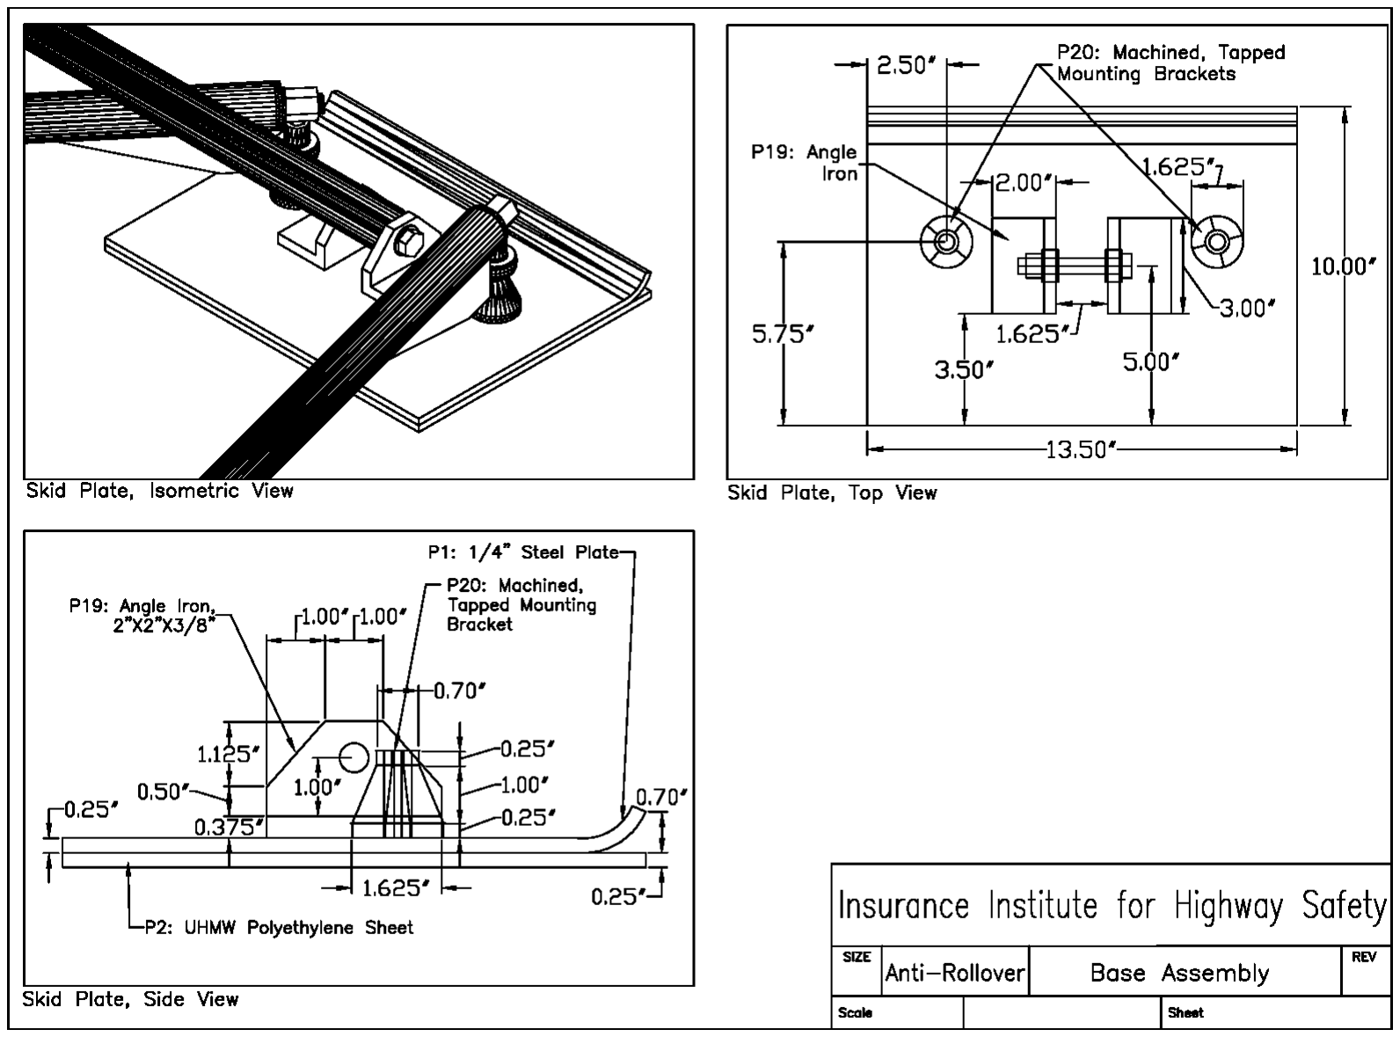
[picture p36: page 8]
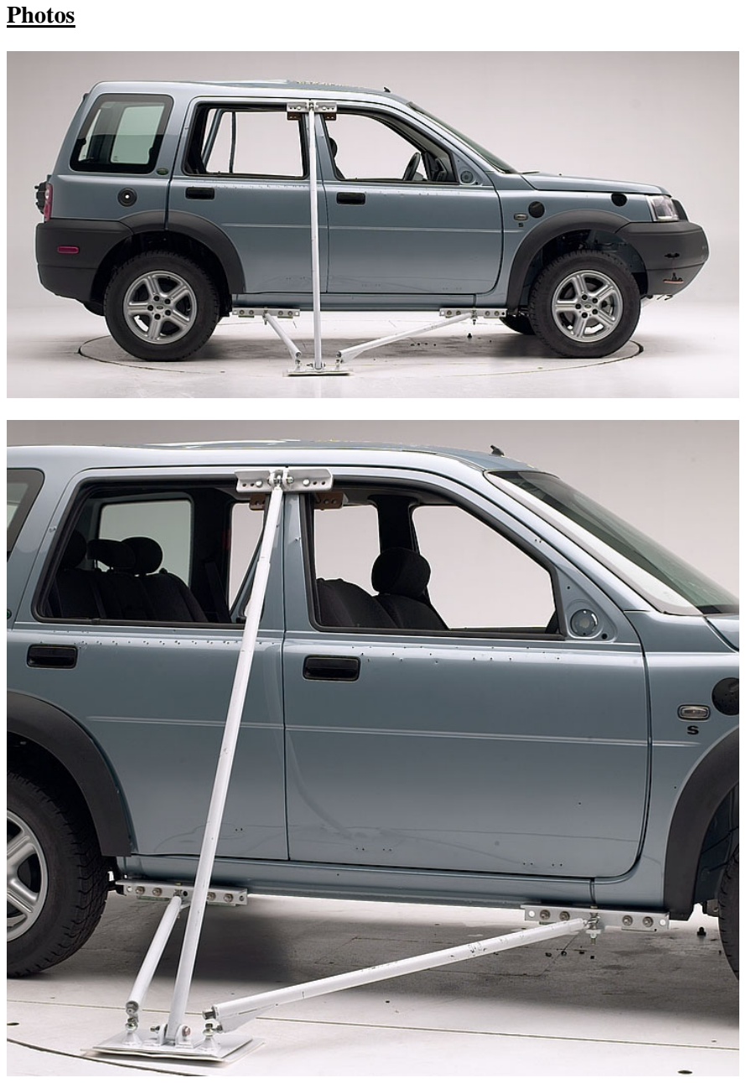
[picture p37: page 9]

Photos

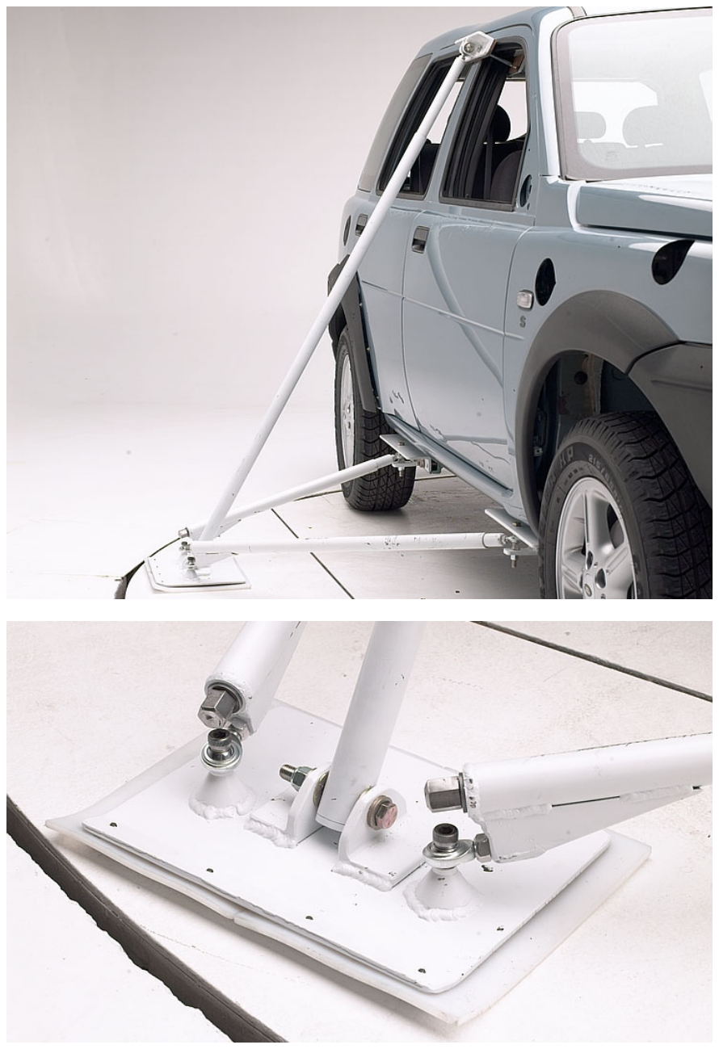
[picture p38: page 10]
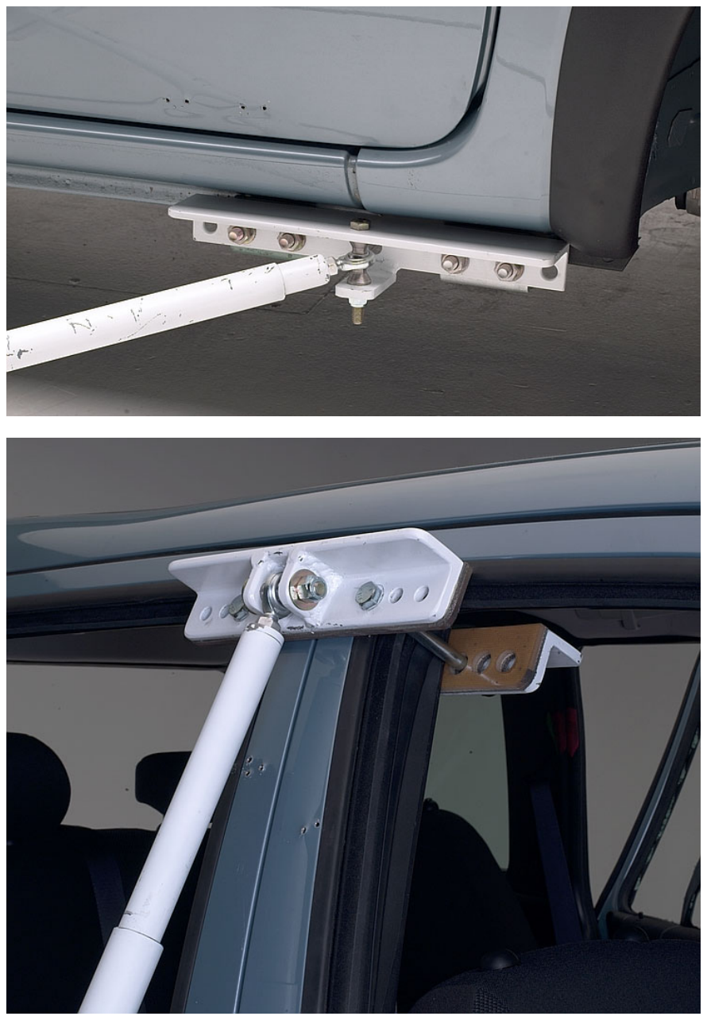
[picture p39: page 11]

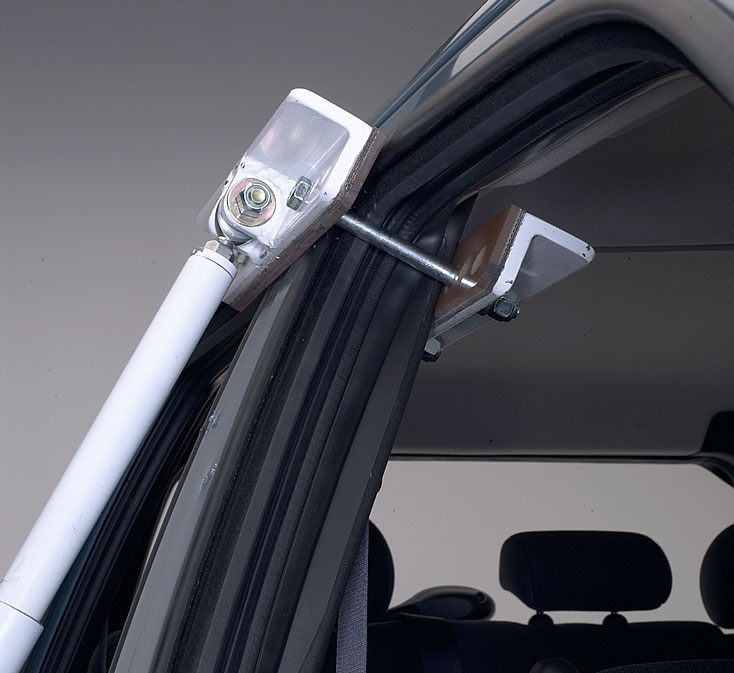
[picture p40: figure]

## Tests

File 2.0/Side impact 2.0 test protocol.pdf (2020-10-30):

## Side Impact Crashworthiness Evaluation 2.0 Crash Test Protocol (Version I)

October 2020

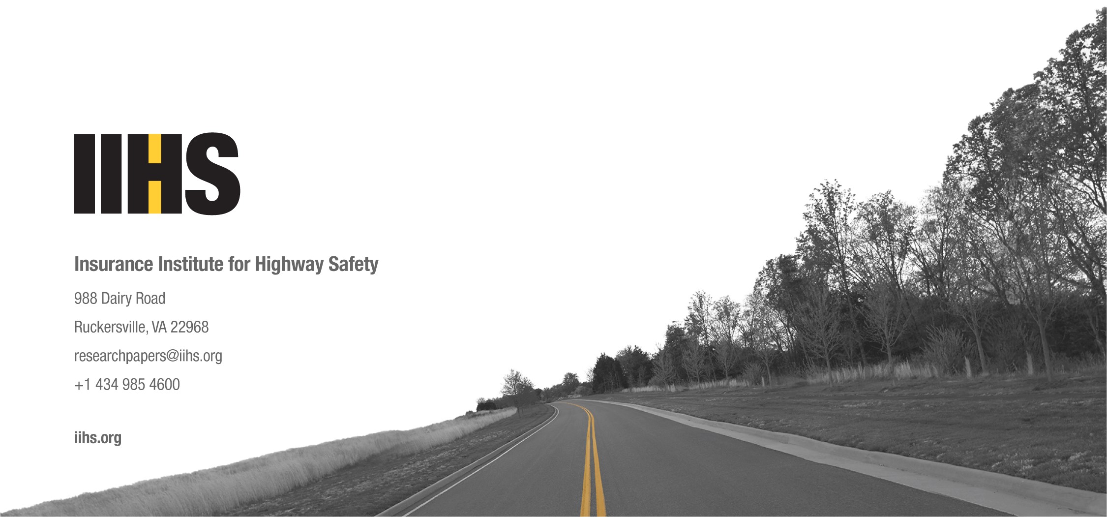
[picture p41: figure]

- 2020 Insurance Institute for Highway Safety | Side Impact Test Protocol 2.0 (Version I)
988 Dairy Rd, Ruckersville, VA 22968. All rights reserved. | October 2020 — 1

CONTENTS

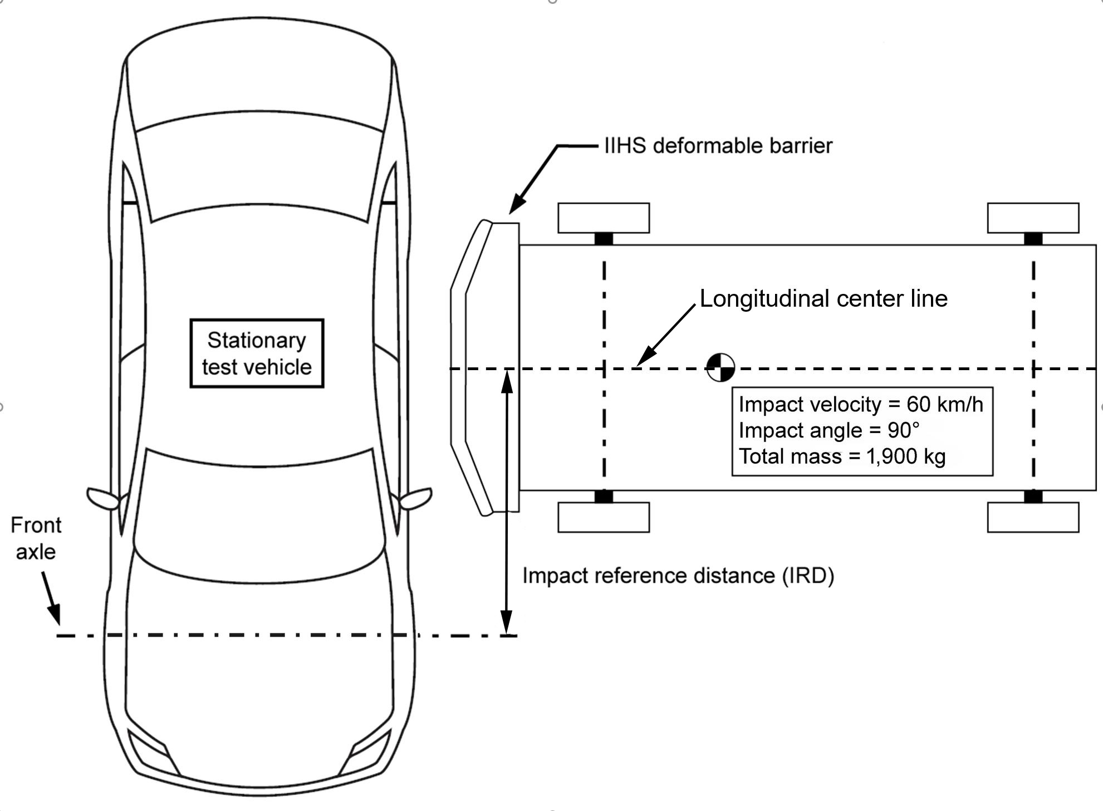
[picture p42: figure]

988 Dairy Rd, Ruckersville, VA 22968. All rights reserved. | October 2020 — 2

### OVERVIEW

Testing procedures outlined in this document are largely similar to those in the previous side impact testing protocol, Side Impact Crash Test Protocol (Version X), with changes to the test speed and moving deformable barrier.
Supporting documents for the Insurance Institute for Highway Safety (IIHS) side impact crash test program are available from the Test protocols and technical information section of the IIHS website.

### IMPACT CONFIGURATION

Side impact crash tests consist of a stationary test vehicle struck on the driver side by a crash cart fitted with a deformable element on the striking face. The 1,900 kg moving deformable barrier (MDB) has an impact velocity of 60 km/h and strikes the vehicle on the driver side at a 90 degree angle. The longitudinal impact point of the barrier on the side of the test vehicle is dependent on the vehicle wheelbase. The impact reference distance (IRD) is defined as the distance rearward from the test vehicle front axle to the centerline of the striking barrier when it first contacts the vehicle (Figure 1).
Figure 1
Moving Deformable Barrier Alignment with Test Vehicle

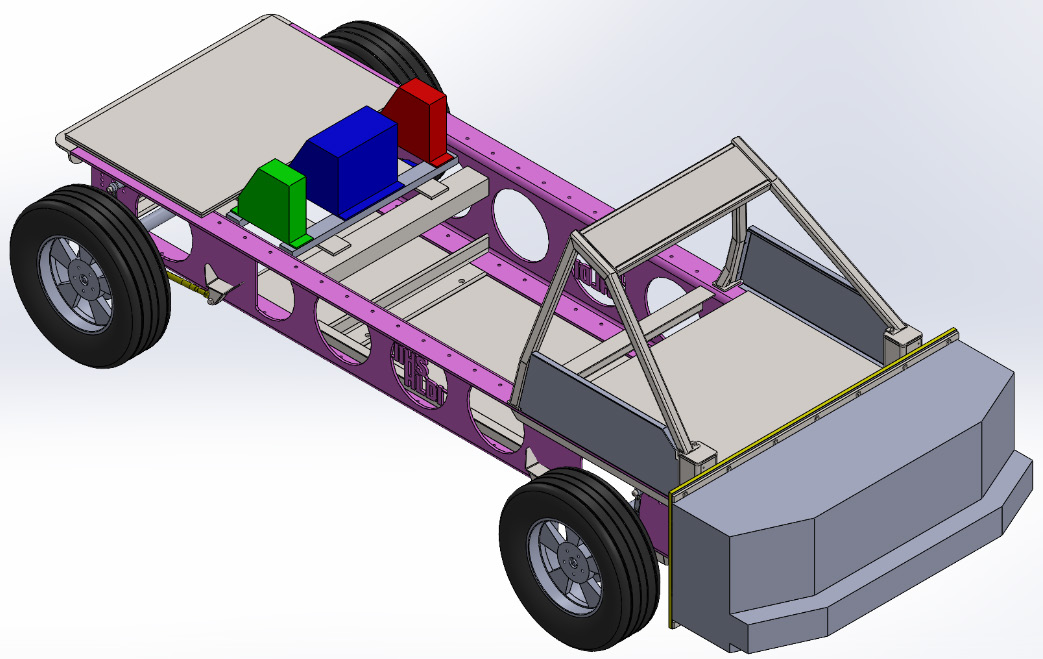
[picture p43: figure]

988 Dairy Rd, Ruckersville, VA 22968. All rights reserved. | October 2020 — 3

The MDB alignment calculation was configured to maximize loading to the occupant compartment. If the alignment calculation allows the flat portion of the MDB face to overlap either the front or rear tires, the impact alignment may be modified to prevent direct loading to these structures early in the crash. Currently, there is no set alignment rule for vehicles that fall into this category, therefore impact alignment is determined on a case-by-case basis. Manufacturers may contact IIHS for impact point determination and/or confirmation of the impact point during the vehicle development process. IRD calculation:
If wheelbase < 250 cm, then IRD = 144.8 cm
If 250 cm ≤ wheelbase ≤ 290 cm, then IRD = (wheelbase ÷ 2) + 19.8 cm
If wheelbase > 290 cm, then IRD = 164.8 cm
The MDB is accelerated by the propulsion system until it reaches the test speed (60 km/h) and then is released from the propulsion system 25 cm before the point of impact with the test vehicle. The impact point tolerance is ± 2.5 cm of the target in the horizontal and vertical axes. The impact speed tolerance is 60 ± 1 km/h. The MDB braking system, which applies the test cart service brakes on all four wheels, is activated 0.2 second after it is released from the propulsion system. The brakes on the test vehicle are not activated during the crash test.
IIHS MDB Properties
The MDB consists of an IIHS deformable aluminum barrier (2.0) and the cart to which it is attached. The crash cart dimensions, mass, and inertial properties are based on those of a midsize SUV (Figure 2). The cart is equipped with suspension at both the front and rear axles, and the wheels are aligned with the longitudinal axis (0 degrees) to allow for perpendicular impact.
The MDB test weight is 1,900 ±5 kg with the deformable element, test instrumentation, camera, and camera mount. The MDB center of gravity in the fully equipped test condition is 1,236 ± 10 mm rearward of the front axle, 0 ± 10 mm from the lateral centerline, and 651 ±10 mm from the ground. The MDB roll (IX), pitch (IY), and yaw (IZ) moments of inertia are 581 kg-m²

, 3,688 kg-m²

, and 4,049 kg-m²
,
respectively.
Figure 2
IIHS Test Cart with Deformable Barrier Element Attached

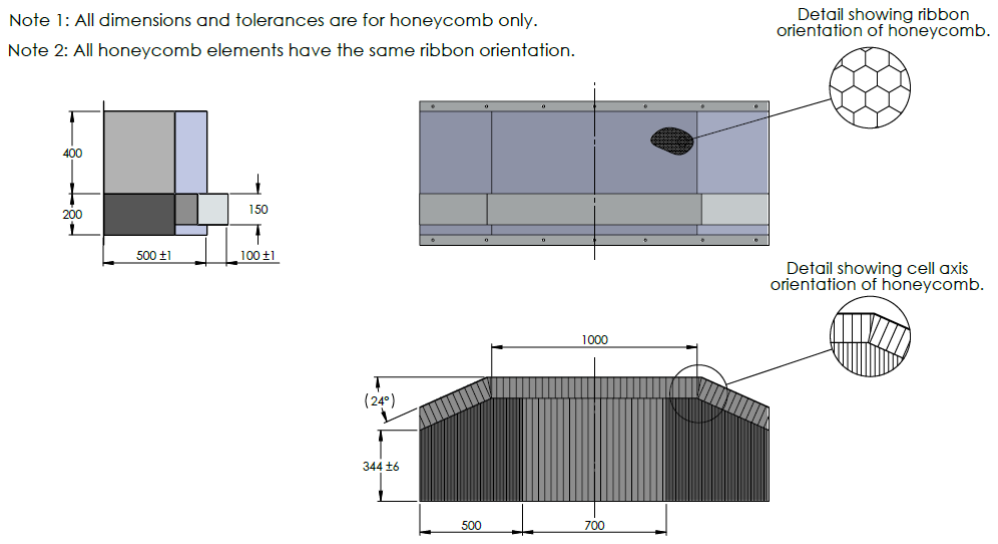
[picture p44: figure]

988 Dairy Rd, Ruckersville, VA 22968. All rights reserved. | October 2020 — 4

The deformable element has a width of 1,700 mm, a height of 600 mm, and a ground clearance of 350 mm when mounted on the test cart (Figure 3).
The IIHS deformable barrier design and performance criteria are documented in the Side Impact Moving Deformable Barrier Specification 2.0 (IIHS, 2020); detailed drawings are also included.
Figure 3
IIHS Deformable Barrier Element (all measurements in millimeters)

Test Vehicle Preparation
Each vehicle is inspected upon arrival at the research center. Vehicles are examined to verify that they are in satisfactory operating condition and to note defects such as prior collision damage, missing parts, maladjustments, or fluid leaks. If directly relevant to testing, such deficiencies are corrected or a replacement vehicle is procured.
Fluids
Gasoline is removed from the fuel tank and fuel lines. The fuel tank then is filled with Stoddard solvent to 90–95% of useable capacity. Purple dye is added to the Stoddard to better identify leaks posttest. The fuel pump is run for a short period to ensure that the Stoddard solvent has filled the fuel lines. Additional fluids may be drained from the vehicle should the vehicle exceed the maximum allowable test weight. High-Voltage Batteries
High-voltage batteries in vehicles with full-electric drivetrains are tested at a state of charge (SoC) of 12.5 ± 2.5%, with a minimum of 25 miles of travel capacity on the battery. To avoid the possibility of the hybrid system attempting to begin a charge cycle, (i.e., engine start), the high-voltage batteries in hybrid vehicles are tested at the minimum SoC recommended by the manufacturer. Maintenance fuses are not removed, but additional precrash and postcrash precautions specified by the vehicle manufacturer are followed. Equipment is added to the high-voltage system in accordance with manufacturer-recommended

988 Dairy Rd, Ruckersville, VA 22968. All rights reserved. | October 2020 — 5

procedures for monitoring electrical isolation as per Federal Motor Vehicle Safety Standard (FMVSS)
305. Thermocouple(s) also are attached to the high-voltage battery to detect temperature increases that may indicate a thermal runaway condition.
Test Vehicle Instrumentation
An aluminum instrumentation rack, which supports the test equipment, is installed in the cargo area of the vehicle. The carpeting in this area is removed to allow access to the floor. If necessary, the spare tire, accessory jack, tool compartments, and third row seats may be removed. The following test equipment is installed on the instrumentation rack located in the cargo area:
12-volt battery and monitoring system: This system supplies electrical power for the data acquisition system (DAS) and a wireless bridge for DAS communication. The system weighs approximately 25 kg. The wireless device for DAS-to-network communication is mounted to the outside of the vehicle and weighs 2 kg. A two-conductor cable connects the 12-volt battery in the instrumentation rack to the vehicle battery terminals.
High-speed camera and onboard lighting power supply: This system supplies electrical power and control to the onboard high-speed video cameras and LED lighting. The weight of the camera/lighting system is approximately 37 kg.
Two camera mount platforms are installed on the nonstruck side of the vehicle at locations adjacent to the front- and rear-passenger window sills; the front and rear platforms weigh 10 and 15 kg, respectively. Three digital onboard high-speed cameras (500 frames per second), along with a camera router, are mounted on the platforms to observe dummy kinematics throughout the crash. Additionally, four LED light fixtures are mounted inside the vehicle.
A plastic block containing an array of high-intensity LEDs is attached to the roof of the vehicle with sheet metal screws. Additional LEDs are placed inside the vehicle in view of the onboard high-speed cameras. A pressure-sensitive tape switch is applied to the driver side of the vehicle such that it makes first contact with the barrier during the crash. Pressure applied to this tape completes an electrical circuit that signals the start of the crash (time-zero) for the data acquisition systems and illuminates all the LEDs.
If floormats are standard or offered as an option through the manufacturer or dealership, they are installed in the driver footwell and left rear-passenger floorpan.
The location of the vehicle precrash longitudinal center of gravity is marked with a photographic target applied to the appropriate top surface of the vehicle (Figure 4).
The front-passenger head restraint and passenger-side windows are removed to prevent possible obstruction of camera views during the test.
If the vehicle is equipped with running boards, they are removed unless they are standard equipment across the entire model line for the specific drive configuration being tested (two-wheel or four-wheel drive).

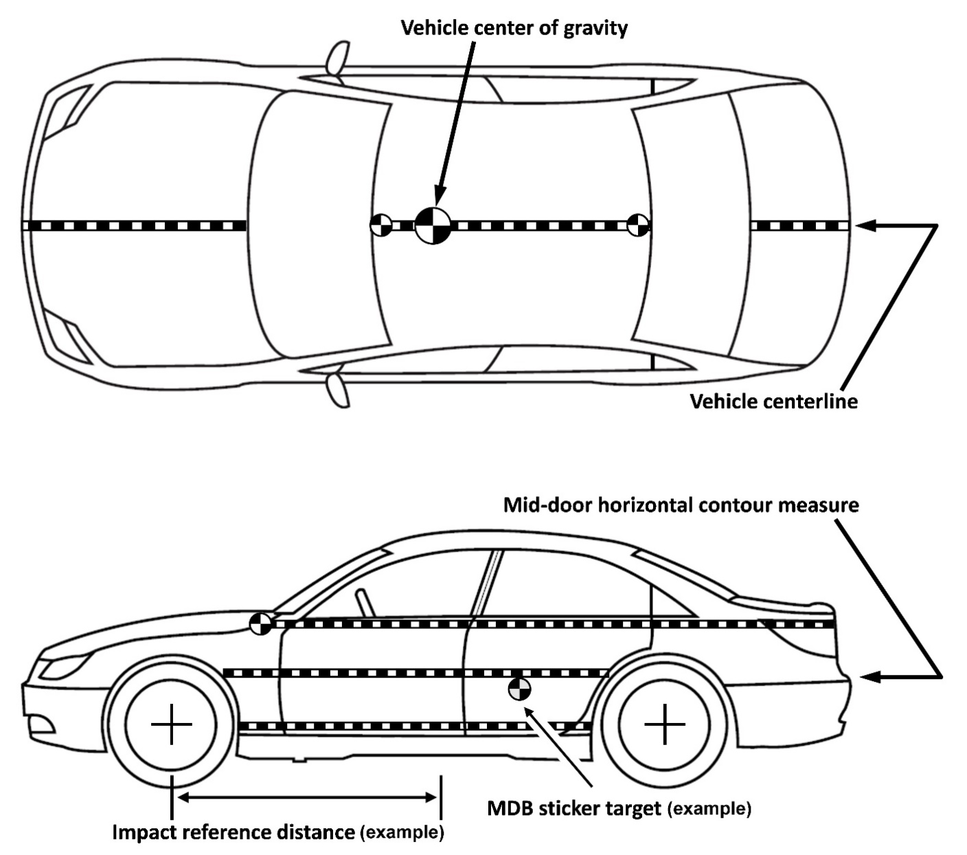
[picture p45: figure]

988 Dairy Rd, Ruckersville, VA 22968. All rights reserved. | October 2020 — 6

Figure 4
Exterior Surface Marking

Attachment of Antiroll Device to Vehicles with a High Center of Gravity
To prevent possible damage to cameras and equipment caused by a rollover subsequent to the side impact, vehicles with a high center of gravity (typically those classified by IIHS as midsize and large SUVs, pickups, or passenger vans) will be tested with an antiroll device attached to the nonstruck side of the vehicle (Figure 5). The antiroll device is made primarily of 4130 Chromoly structural tubing and weighs 42.5 kg. It attaches to the vehicle where the roof rail intersects the B-pillar and at two points on the pinch welds under the door sill. The device is designed to allow the vehicle to rotate up to 5 degrees before further rotation is countered by a spring (14.8 kN/m) in the upper support member, which will allow an additional 5 degrees of rotation before bottoming out. Detailed drawings of the antiroll device are available upon request.

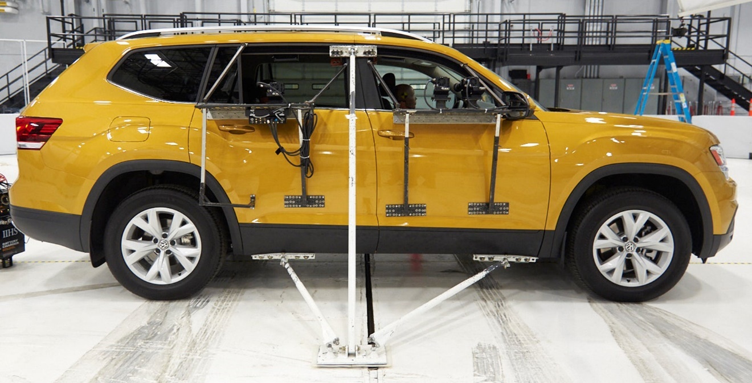
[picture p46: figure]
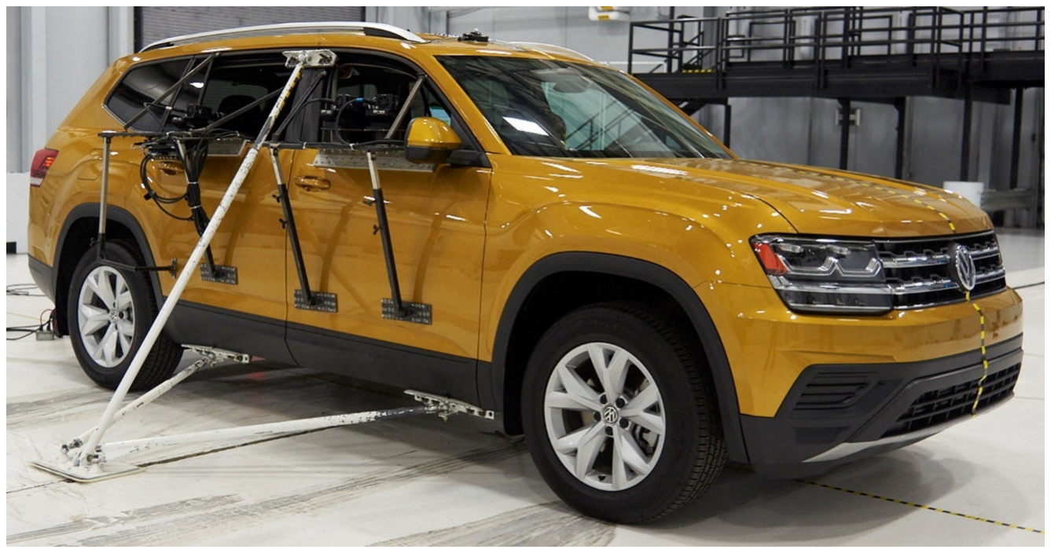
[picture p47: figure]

988 Dairy Rd, Ruckersville, VA 22968. All rights reserved. | October 2020 — 7

Figure 5
Antiroll Device for Tests of Midsize and Large SUVs, Pickups, and Passenger Vans

Test Vehicle Mass and Weight Distribution
The test weight of the vehicle, which includes the vehicle instrumentation, three cameras, and two SID-IIs dummies, is 150–225 kg greater than the measured curb weight of the vehicle (as delivered from the dealer with full fluid levels). If the vehicle test weight needs to be increased to fall within the range, ballast weight is distributed in a manner that comes closest to replicating the original front/rear and left/right weight distributions of the vehicle. If the vehicle test weight needs to be decreased, nonessential, nonstructural items are removed from the rear of the vehicle.

988 Dairy Rd, Ruckersville, VA 22968. All rights reserved. | October 2020 — 8

Driver Seat and Driving Control Placement
The driver seat and adjustable steering controls are adjusted according to the Guidelines for Using the UMTRI ATD Positioning Procedure for ATD and Seat Positioning (Version V) (IIHS, 2004). The outboard upper seat belt anchorage point (if adjustable) is set in the full-down position, unless otherwise specified by the test vehicle manufacturer. After the driver seat has been adjusted, the latching mechanism is examined to note whether all of its components are interlocked. If partial interlocking is observed and normal readjustment of the seat does not correct the problematic misalignment, the condition is noted and the test is conducted without repairing the mechanism. The right front-passenger seat is set to match the position of the driver seat.
The driver head restraint (if manually adjustable) is set in the full-down position, unless otherwise specified by the test vehicle manufacturer. The locking mechanism for adjusting the head restraint height (if equipped) is examined to ensure the mechanism has engaged. All manually adjustable, head restraint tilting mechanisms are adjusted to their full-rearward position.
The manually adjustable inboard armrest for the driver seat (if equipped) is moved to its lowered position. For vehicles equipped with multiple locking armrest positions, the position that results in the top surface of the armrest being closest to parallel with the ground is chosen. When seats have inboard and outboard armrests, both are placed in the lowered position.
Rear-Passenger Seat Placement
If applicable, the rear-passenger seat is positioned according to the Dummy Seating Procedure for Rear Outboard Positions (IIHS, 2020).
If manually adjustable, the rear-passenger head restraint is set in the full-down position, unless otherwise specified by the test vehicle manufacturer. In cases where the head restraint can be lowered for stowage or positioned for non-use, it shall be set to the first usable locking position. All manually adjustable head restraint tilting mechanisms are adjusted to their full-rearward position.
The manually adjustable inboard armrest for the rear seat (if equipped) is moved to its lowered position. For vehicles equipped with multiple locking armrest positions, the position that results in the top surface of the armrest being closest to parallel with the ground is chosen. When seats have inboard and outboard armrests, both are placed in the lowered position.
Side Windows and Door Locks
The nonstruck side doors are fully latched and locked, whereas the struck side doors are fully latched but not locked. However, if the vehicle is equipped with automatic locking doors that cannot be set to remain unlocked when the vehicle is in forward motion, the struck side door locks are kept in their automatic state. The front and rear driver-side windows are fully raised.
Transmission and Ignition
The ignition is turned to its on position, and the transmission is shifted into its neutral position prior to the test. The parking brake is activated. The front left tire is chocked to prevent the vehicle from moving prior to the test.
Vehicle Ride Height
If the vehicle has an adjustable suspension or is equipped with automatic leveling, those systems are deactivated. The ride height will be set to the default/vehicle parked condition.

988 Dairy Rd, Ruckersville, VA 22968. All rights reserved. | October 2020 — 9

Vehicle Active Side Crash Safety Systems
If the vehicle has an active safety system designed for crash protection in similar crash configurations to this laboratory test, such as an active chassis lift, seat bolster deployment, external airbag, or other technology, all reasonable efforts are made to test with the feature activated. For systems that require test setup modifications, decisions are made on a case-by-case basis. External or manual triggering of systems is not permitted.
Crash Dummy Preparation and Setup
A 5th percentile female SID-IIs dummy is positioned in the driver seat according to the Guidelines for Using the UMTRI ATD Positioning Procedure for ATD and Seat Positioning (Version V) (IIHS, 2004). A second SID-IIs dummy is positioned in the left rear seat according to the Dummy Seating Procedure for Rear Outboard Positions (IIHS, 2020).
Standard Build Level D SID-IIs (Humanetics Innovative Solutions, 2011) dummies are used for the IIHS side impact program. The dummy has been modified by removing the upper and lower shoulder rib stops on the spine box (Humanetics Innovative Solutions, Inc., part numbers 180-3369 and 180-3370). Removal of the shoulder rib stops restores the shoulder deflection to the range that was allowable in the Standard Build Level C SID-IIs. The Build Level D shoulder potentiometer (Humanetics Innovative Solutions, Inc., part number 180-3381) has been replaced with a potentiometer (Humanetics Innovative Solutions, Inc., part number 180-3382) that has a longer travel range. Photographic targets are placed on both sides of the head to mark the location of its center of gravity.
The dummies used in these tests are certified according to 49 CFR 572 (V) after being subjected to no more than five crash tests. Additionally, the shoulder, thorax, and abdomen regions are individually recertified if deflections recorded during a test exceed 50 mm or if postcrash inspection reveals damage. All visible damage is repaired before the dummy is used again.
The dummies and vehicle are kept in a climate-controlled area in the crash hall where the temperature is maintained at 20.0–22.2 degrees Celsius and the relative humidity at 10–70% for at least 16 hours prior to the test. The driver and rear-passenger seat belts are fastened around the dummies. For vehicles with continuous-loop lap/shoulder seat belts, the slack from the lap portion of the driver seat belt is removed, and the webbing is pulled fully out of the retractor and allowed to retract under tension a total of four times. The lap belt slack then is removed again with a small pulling force. For vehicles with separate lap and shoulder seat belt retractors, the webbing from each is pulled fully out of the retractor and allowed to retract under tension a total of four times. Prior to the crash, the heads of both dummies are colored with grease paint to facilitate postcrash identification of impacts with the vehicle interior and/or the striking barrier face.
Photography
Still Photography
The precrash and postcrash conditions of each test vehicle are photographed. Two precrash and two postcrash views show the side and left front quarter of the test vehicle. Additional photographs document the precrash position of the driver and rear-passenger dummies.
Three standard views each of the vehicle and MDB together in their postcrash positions, of the struck side of the vehicle, and of the MDB face are recorded. Additional photographs document the postcrash positions of the driver and rear-passenger dummies, as well as any paint transfer areas due to dummy contact with the vehicle or MDB. Once the dummies are removed from the vehicle, both seating

988 Dairy Rd, Ruckersville, VA 22968. All rights reserved. | October 2020 — 10

compartment areas are photographed as a means of illustrating vehicle intrusion. Additional photographs are taken with the struck side doors removed.
High-Speed Motion Picture Photography
Motion picture photography is made of the test with 10 high-speed digital imagers along with real-time cameras. The coordinates and lens focal length of each offboard camera are listed in Table 1. The camera view and focal length of the onboard high-speed cameras are listed in Table 2. All high-speed imagers record at 500 frames per second. The positions of the offboard and onboard cameras are illustrated in Figures 6A and 6B, respectively.
Table 1
Crash Hall High-Speed Phantom Cameras – Coordinates, Focal Points, and Settings

Camera Position

A

Overhead

B

Left Side
Oblique

C

Front

D

Rear
Oblique

E
Front
Oblique
(driver)

F
Front
Oblique
(pass)
Coordinate X (cm) | −16 | −536 | −33 | −320 | 415* | 415*
Coordinate Y (cm) | −33 | 1350 | 768 | −510 | 740* | 740*
Coordinate Z (cm) | 910 | 149 | 194 | 140 | 146 | 146
Focal length (mm) | 35 | 50 | 95 | 75 | 135 | 135
*Varies by vehicle size and type

Table 2
Onboard High-Speed IDT Digital Cameras – Focal Points and Settings

Camera Position

G

Centered
On MDB

H
Front-Passenger
Window Sill

I
Front-Passenger
Window Sill

J
Rear-Passenger
Window Sill
Focal point | Impact from perspective of the MDB | Oblique view of driver and passenger | Lateral view of driver | Lateral view of passenger
Focal length (mm) | 8.5 | 12 | 12 | 12

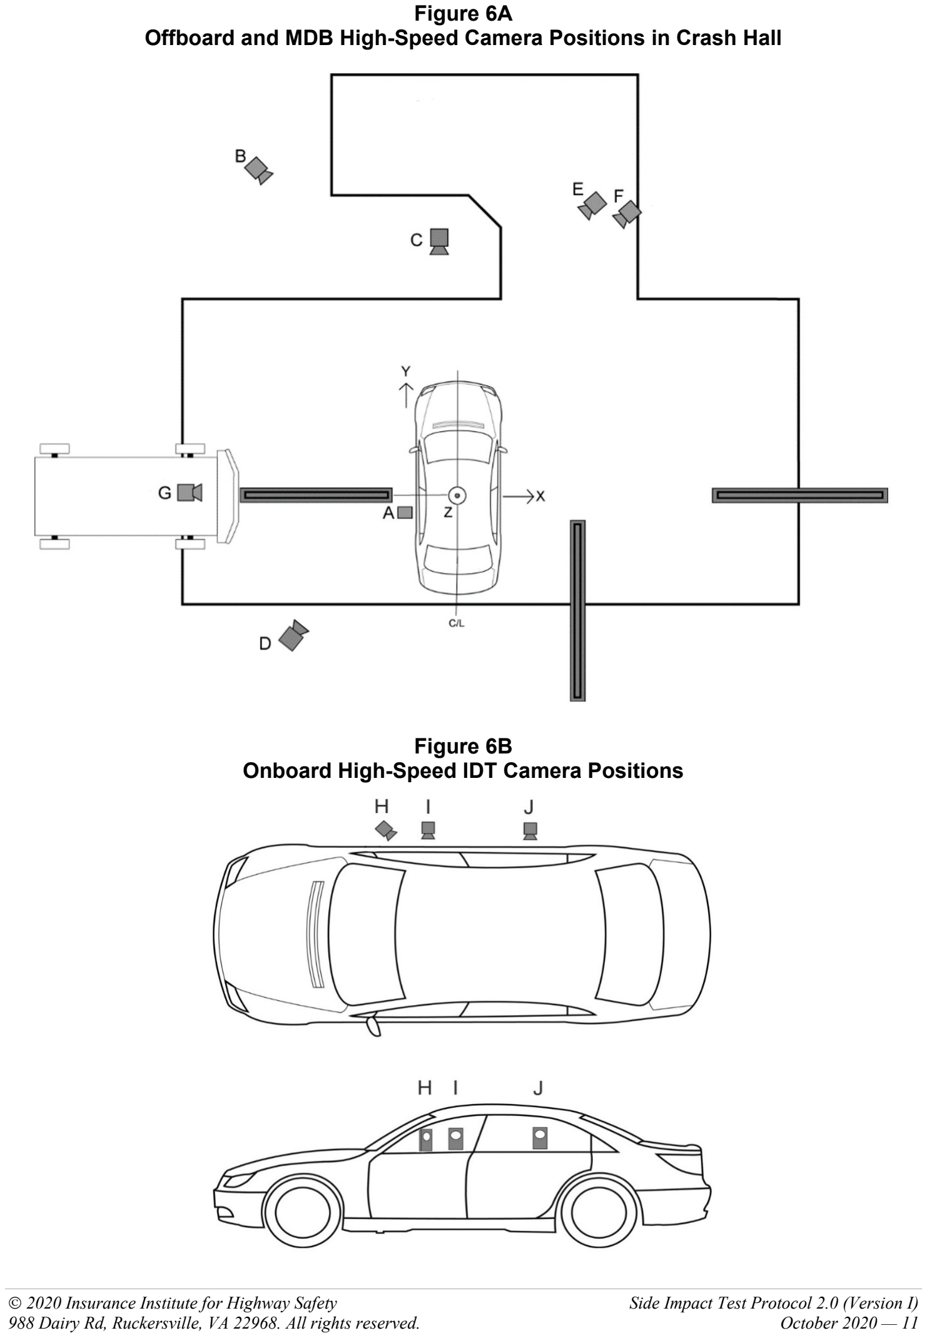
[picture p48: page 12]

988 Dairy Rd, Ruckersville, VA 22968. All rights reserved. | October 2020 — 11

Figure 6A
Offboard and MDB High-Speed Camera Positions in Crash Hall

Figure 6B
Onboard High-Speed IDT Camera Positions

988 Dairy Rd, Ruckersville, VA 22968. All rights reserved. | October 2020 — 12
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

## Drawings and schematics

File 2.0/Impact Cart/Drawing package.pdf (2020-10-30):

A4 | THIRD ANGLE PROJECTION | UNLESS OTHERWISE SPECIFIED: | | NAME | DATE | Insurance Institute for Highway Safety 988 Dairy Rd, Ruckersville, VA 22968 (434) 985-4600 DESIGN/ENGR
INCHES [MILLIMETERS] DIMENSIONS: | IIHS SIDE IMPACT CART

C. O'BRIEN | 2/2020

DRAWN | W. SPIVEY | 9/2020

CHECKED | R. JONES | 9/2020

DO NOT SCALE DRAWING

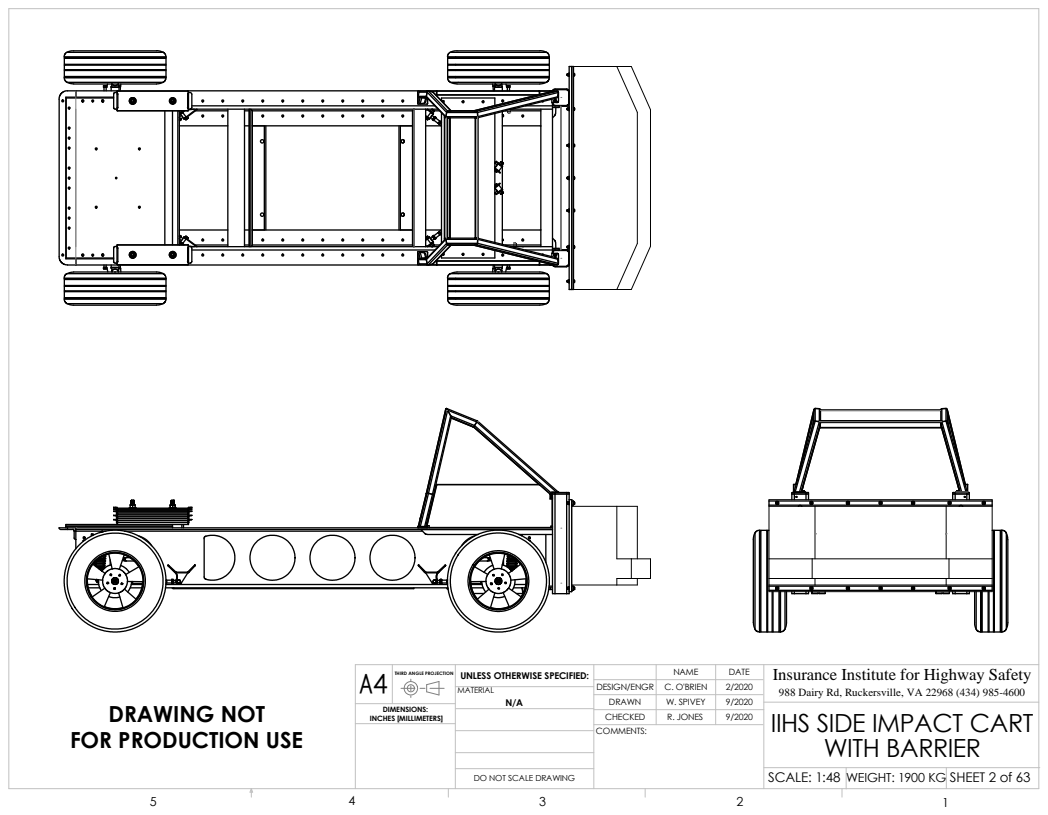
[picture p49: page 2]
SCALE: 1:48; WEIGHT: 1900 KG; COMMENTS:; MATERIAL; INCHES [MILLIMETERS] DIMENSIONS:; 9/2020 DRAWING NOT

A4 | THIRD ANGLE PROJECTION | UNLESS OTHERWISE SPECIFIED: | | NAME | DATE | Insurance Institute for Highway Safety

C. O'BRIEN | 2/2020 | 988 Dairy Rd, Ruckersville, VA 22968 (434) 985-4600 DESIGN/ENGR
DRAWN | W. SPIVEY
CHECKED | R. JONES | 9/2020

FOR PRODUCTION USE

IIHS SIDE IMPACT CART
WITH BARRIER

A4 | THIRD ANGLE PROJECTION | UNLESS OTHERWISE SPECIFIED: | | NAME | DATE | Insurance Institute for Highway Safety
INCHES [MILLIMETERS] | WELDMENT COMPLETE

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

9/2020 DRAWING NOT
FOR PRODUCTION USE

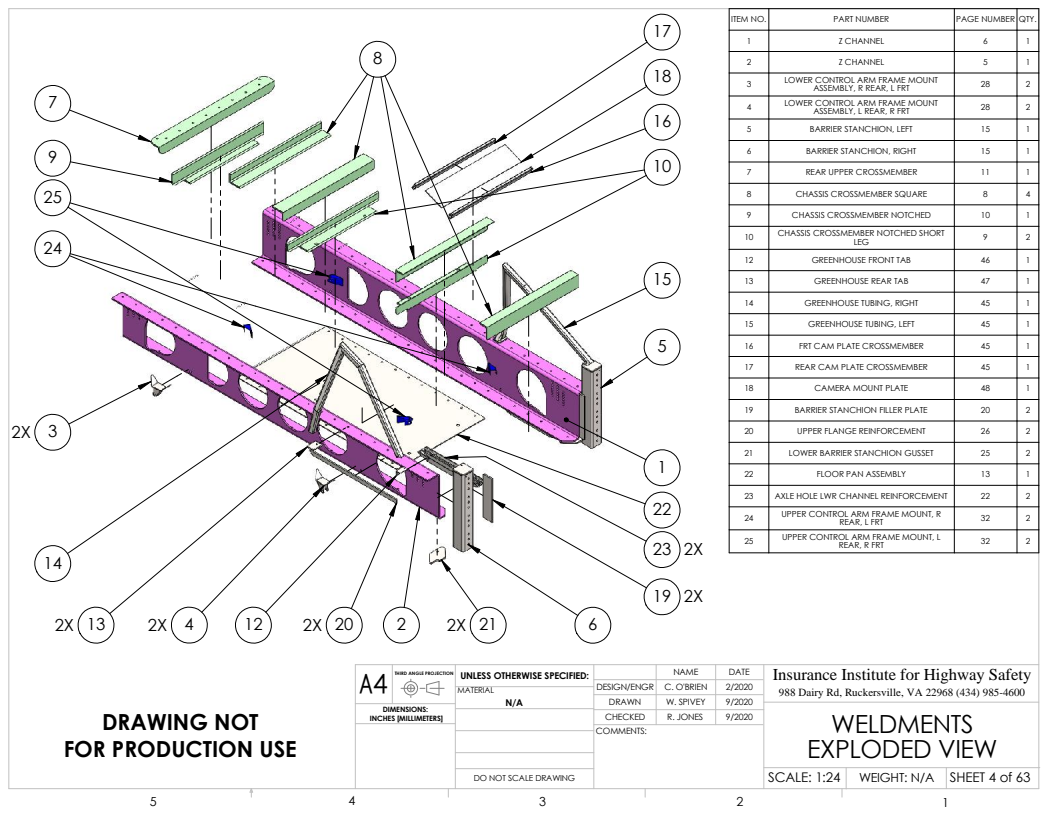
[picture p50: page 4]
SCALE: 1:24; WEIGHT: N/A; COMMENTS:; MATERIAL; 9/2020 DIMENSIONS:

ITEM NO. | PART NUMBER Z CHANNEL | PAGE NUMBER 6 | QTY. 1 1

2 | Z CHANNEL | 5 | 1
3 | LOWER CONTROL ARM FRAME MOUNT ASSEMBLY, R REAR, L FRT | 28 | 2

4 | LOWER CONTROL ARM FRAME MOUNT ASSEMBLY, L REAR, R FRT | 28 | 2

5 | BARRIER STANCHION, LEFT | 15 | 1

6 | BARRIER STANCHION, RIGHT | 15 | 1

7 | REAR UPPER CROSSMEMBER | 11 | 1

8 | CHASSIS CROSSMEMBER SQUARE | 8 | 4

9 | CHASSIS CROSSMEMBER NOTCHED | 10 | 1
10 | CHASSIS CROSSMEMBER NOTCHED SHORT LEG | 9 | 2

12 | GREENHOUSE FRONT TAB | 46 | 1

13 | GREENHOUSE REAR TAB | 47 | 1

14 | GREENHOUSE TUBING, RIGHT | 45 | 1

15 | GREENHOUSE TUBING, LEFT | 45 | 1

16 | FRT CAM PLATE CROSSMEMBER | 45 | 1

17 | REAR CAM PLATE CROSSMEMBER | 45 | 1

18 | CAMERA MOUNT PLATE | 48 | 1

19 | BARRIER STANCHION FILLER PLATE | 20 | 2

20 | UPPER FLANGE REINFORCEMENT | 26 | 2

21 | LOWER BARRIER STANCHION GUSSET | 25 | 2

22 | FLOOR PAN ASSEMBLY | 13 | 1

23 | AXLE HOLE LWR CHANNEL REINFORCEMENT | 22 | 2
24 | UPPER CONTROL ARM FRAME MOUNT, R REAR, L FRT | 32 | 2

25 | UPPER CONTROL ARM FRAME MOUNT, L REAR, R FRT | 32 | 2

A4 | THIRD ANGLE PROJECTION | UNLESS OTHERWISE SPECIFIED: | | NAME | DATE | Insurance Institute for Highway Safety
INCHES [MILLIMETERS] | WELDMENTS EXPLODED VIEW

C. O'BRIEN | 2/2020 | 988 Dairy Rd, Ruckersville, VA 22968 (434) 985-4600 DESIGN/ENGR
DRAWN | W. SPIVEY | 9/2020
CHECKED | R. JONES

DRAWING NOT
FOR PRODUCTION USE

THIRD ANGLE PROJECTION ⁰

CUT AFTER BENDING

A4 | UNLESS OTHERWISE SPECIFIED: | | NAME | DATE | Insurance Institute for Highway Safety
DIMENSIONS: INCHES [MILLIMETERS] | RIGHT Z-CHANNEL

C. O'BRIEN | 1/3/2020 | 988 Dairy Rd, Ruckersville, VA 22968 (434) 985-4600 DESIGN/ENGR
DRAWN | R. JONES | 2/6/2020
CHECKED

DRAWING NOT
FOR PRODUCTION USE

CUT AFTER BENDING

A4 | THIRD ANGLE PROJECTION | UNLESS OTHERWISE SPECIFIED: | | NAME | DATE | Insurance Institute for Highway Safety
INCHES [MILLIMETERS] | LEFT Z-CHANNEL

C. O'BRIEN | 1/3/2020 | 988 Dairy Rd, Ruckersville, VA 22968 (434) 985-4600 DESIGN/ENGR
DRAWN | R. JONES
CHECKED

DRAWING NOT
FOR PRODUCTION USE

SCALE: VARIES WEIGHT: 197 KG

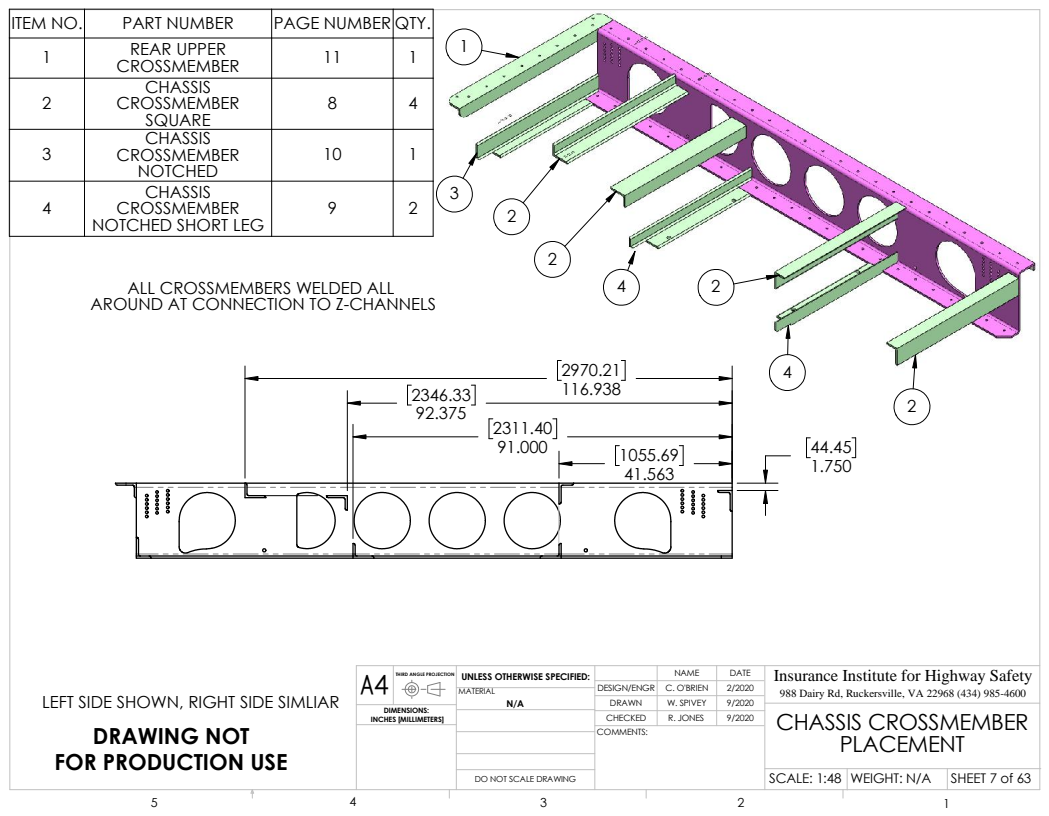
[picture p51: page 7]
SCALE: 1:48; WEIGHT: N/A; COMMENTS:; MATERIAL; 9/2020 DIMENSIONS:

ITEM NO. | PART NUMBER | PAGE NUMBER QTY.
1 | REAR UPPER CROSSMEMBER | 11 | 1
2 | CHASSIS CROSSMEMBER SQUARE | 8 | 4

3 | CHASSIS CROSSMEMBER NOTCHED | 10 | 1

4 | CHASSIS CROSSMEMBER NOTCHED SHORT LEG | 9 | 2

ALL CROSSMEMBERS WELDED ALL
AROUND AT CONNECTION TO Z-CHANNELS

A4 | THIRD ANGLE PROJECTION | UNLESS OTHERWISE SPECIFIED: | | NAME | DATE | Insurance Institute for Highway Safety
INCHES [MILLIMETERS] | CHASSIS CROSSMEMBER PLACEMENT

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

LEFT SIDE SHOWN, RIGHT SIDE SIMLIAR
DRAWING NOT
FOR PRODUCTION USE

FROM 5X3.5X.5 ANGLE
DRAWING NOT
FOR PRODUCTION USE

A4 | THIRD ANGLE PROJECTION | UNLESS OTHERWISE SPECIFIED: | | NAME | DATE | Insurance Institute for Highway Safety
INCHES [MILLIMETERS] | CHASSIS CROSSMEMBER SQUARE

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

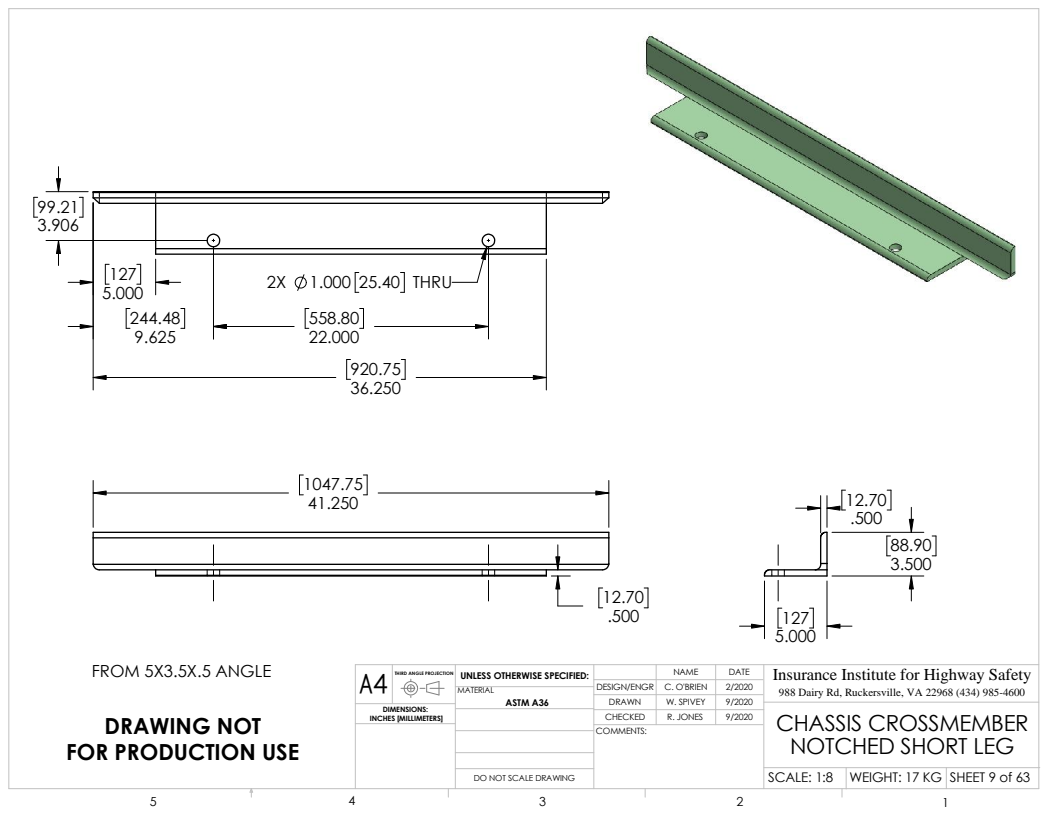
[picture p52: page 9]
ASTM A36; SCALE: 1:8; WEIGHT: 17 KG; COMMENTS:; MATERIAL; 9/2020 DIMENSIONS:; THRU 127
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

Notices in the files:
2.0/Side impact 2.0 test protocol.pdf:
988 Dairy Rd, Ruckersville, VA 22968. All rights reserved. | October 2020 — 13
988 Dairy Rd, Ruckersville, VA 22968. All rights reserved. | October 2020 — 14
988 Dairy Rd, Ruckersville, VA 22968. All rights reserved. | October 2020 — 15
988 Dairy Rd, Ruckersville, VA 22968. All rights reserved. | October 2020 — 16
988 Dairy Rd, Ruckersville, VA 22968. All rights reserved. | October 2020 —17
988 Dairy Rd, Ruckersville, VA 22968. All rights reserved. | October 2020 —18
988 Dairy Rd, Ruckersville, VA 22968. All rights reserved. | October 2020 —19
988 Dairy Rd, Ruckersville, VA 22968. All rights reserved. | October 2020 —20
